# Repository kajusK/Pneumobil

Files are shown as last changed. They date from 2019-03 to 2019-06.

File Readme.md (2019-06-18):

Pneumobil control and telemetry system
======================================

This repository contains source code and board design for control system
of pneumobil racing car Falcon from Brno University of Technology.

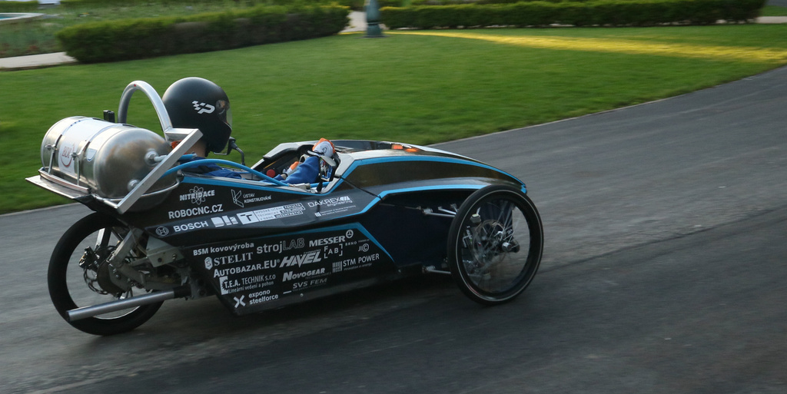
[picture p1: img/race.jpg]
race


Parts
-----
 * HMI - Human Machine Interface - LCD touch screen and telemetry board
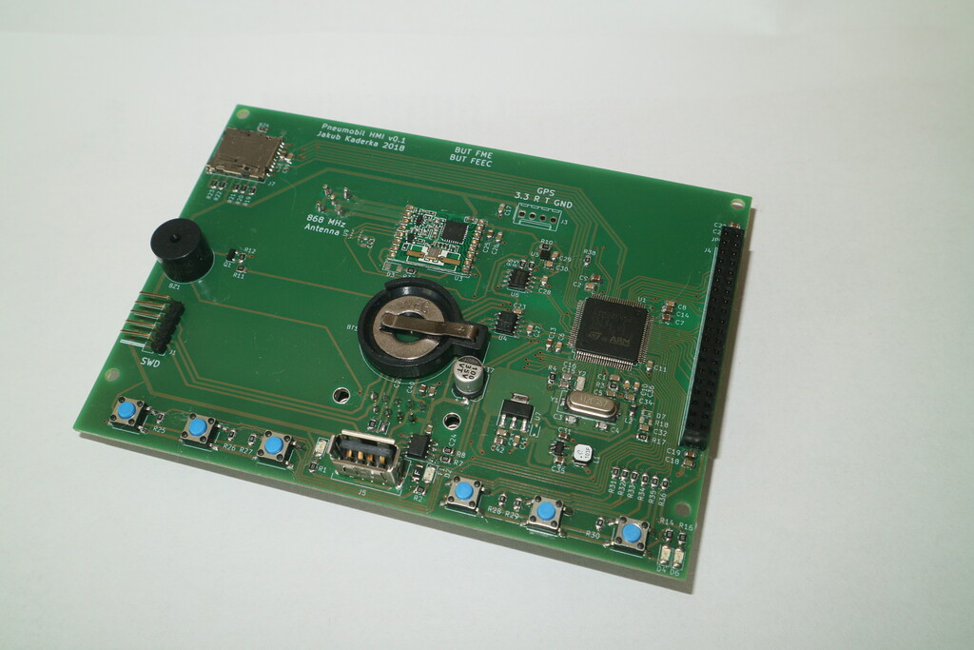
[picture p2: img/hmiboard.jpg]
hmi

 * ECU - Engine Control Unit - Control system of pneumatic propulsion system
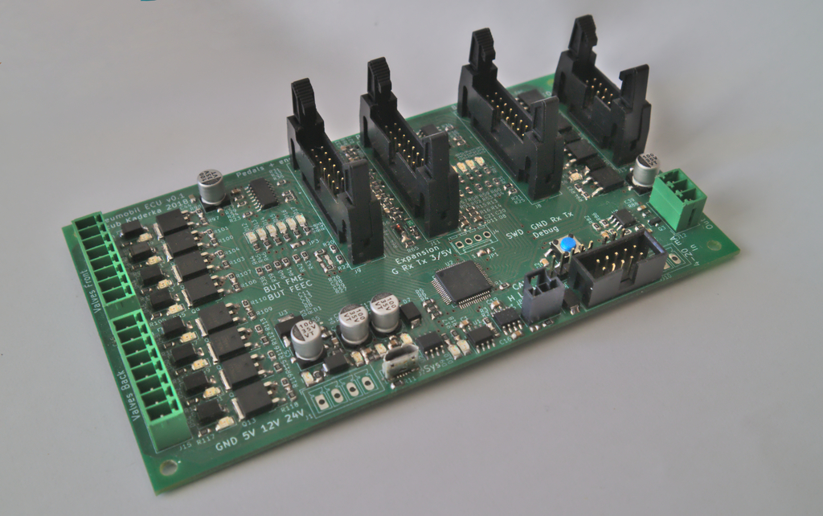
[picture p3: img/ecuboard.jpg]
ecu

 * SDU - Speed Display Unit
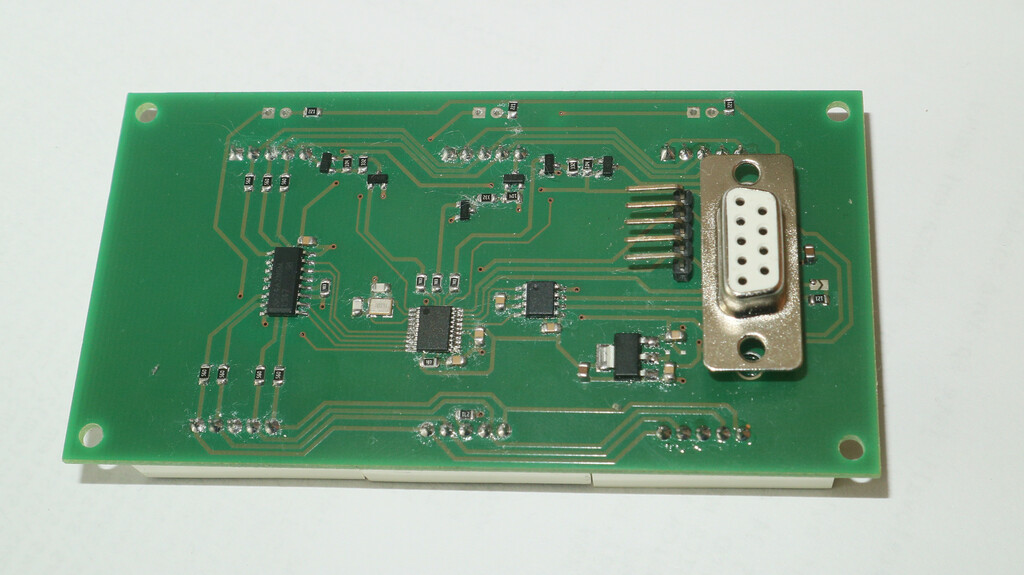
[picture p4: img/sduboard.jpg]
sdu

 * PSU - Power Supply Unit
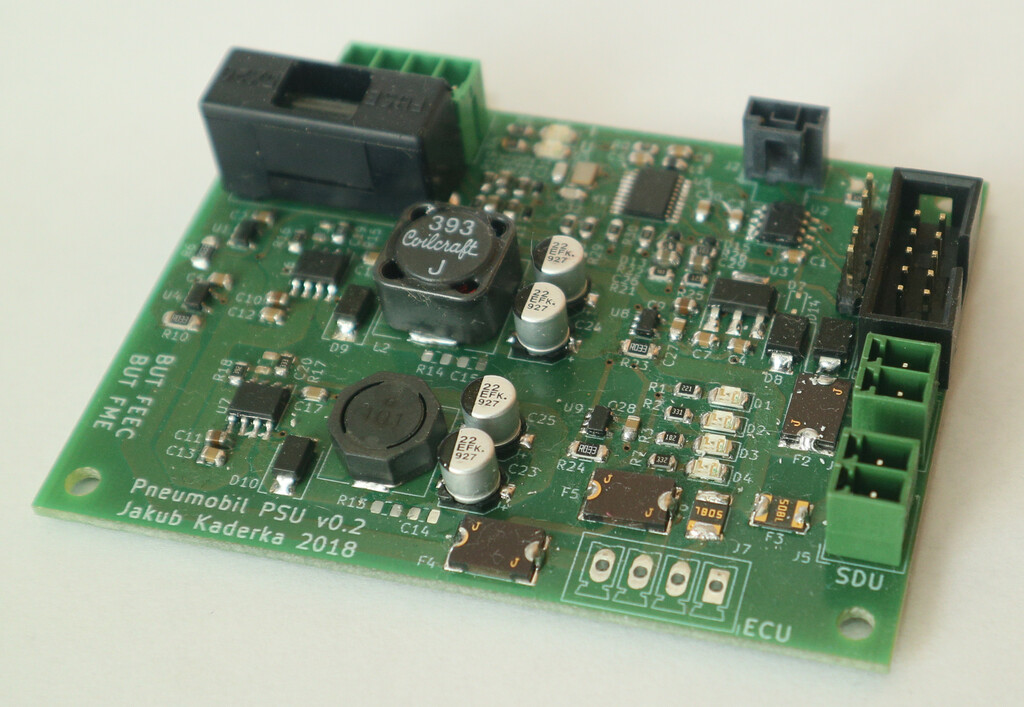
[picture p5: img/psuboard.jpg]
psu

 * Radio2usb - Telemetry receiving system
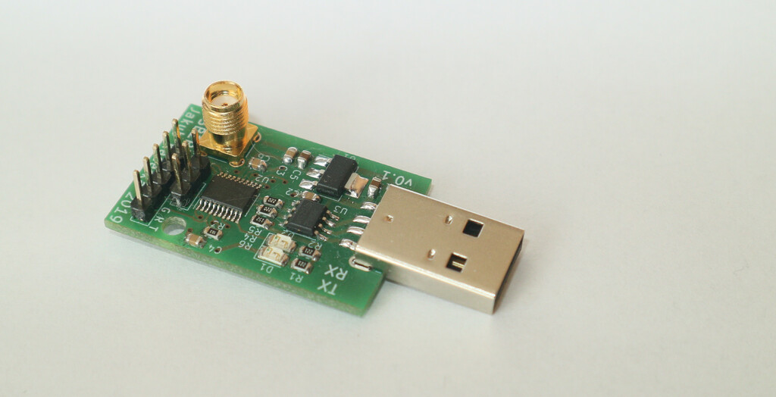
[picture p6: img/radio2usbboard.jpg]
r2usb


Description
-----------
Placement in the car
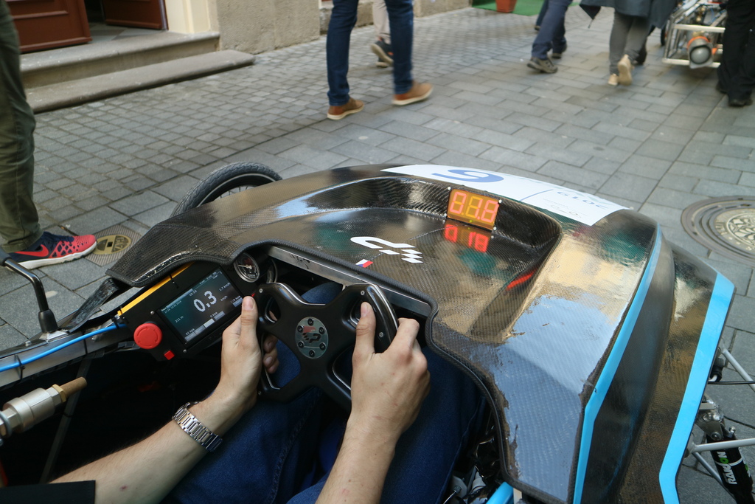
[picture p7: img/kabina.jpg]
cabin

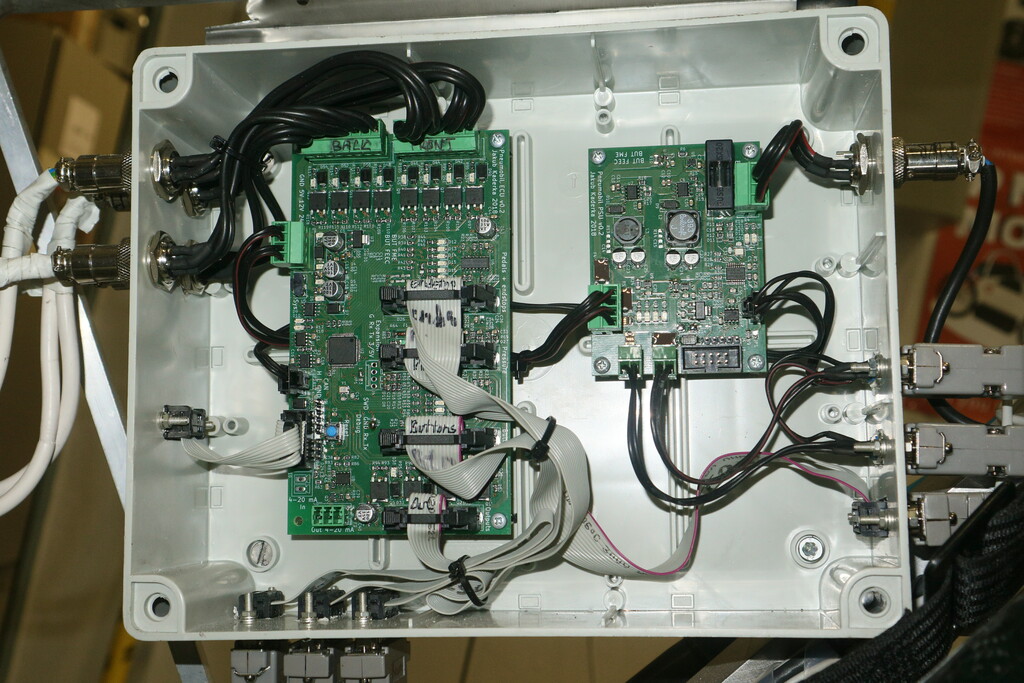
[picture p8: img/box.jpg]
box


Python telemetry program
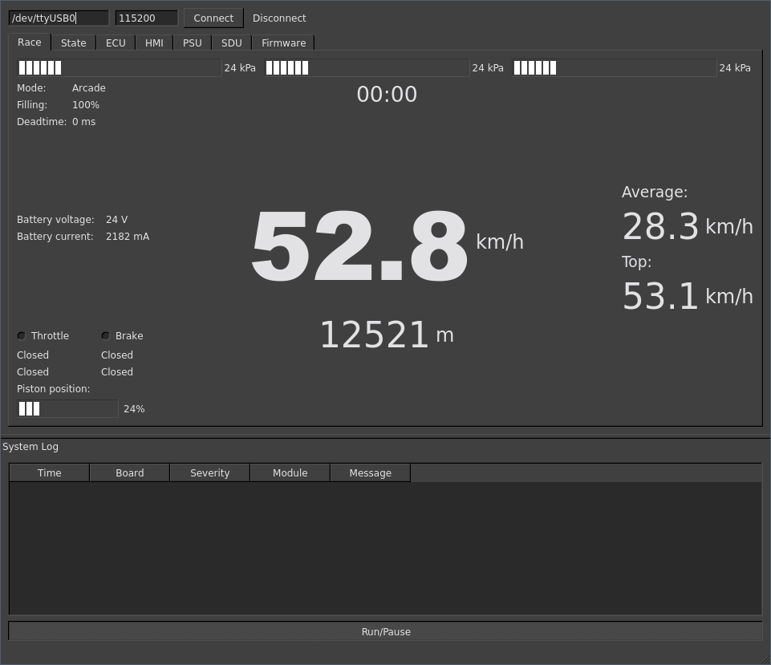
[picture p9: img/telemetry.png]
telemetry


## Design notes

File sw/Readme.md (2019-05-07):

Brief
=====

This directory contains various PC side tools to be used for development, code
generation, debugging, etc.

Directories
===========
generators
----------
Scripts from this directory are used to generate header files and definitions
from specifications in doc/specs

Run generators/genall.py to regenerate all generated sources

tools
-----
Various tools, e.g. CRC lookup table generation, code checking, etc.

telemetry
---------
Telemetry tool for displaying current car state transferred wirelessly, debug
interface,....

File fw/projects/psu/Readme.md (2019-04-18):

Setting option bits
===================

Pin PB8 serves as a BOOT0 pin by default, to use it as GPIO, option bits must
be configured - use STM32CubeProgrammer to uncheck Boot_Sel bit

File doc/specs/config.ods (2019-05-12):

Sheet: ECU_config
Name | Type | Default | Comment
piston_len | uint | 0 | Piston len in encoder steps
encoder_invert | bool | 0 | Invert direction of encoder counting
pneu_non_block | bool | 0 | Ignore checking pneu enabled
wheel_dia_mm | uint | 540 | Diameter of the wheel where the speed sensor is placed
pulses_per_wheel_rotation | uint | 60 | Amount of holes in the shade on the back wheel for speed measurement (pulses generated in single rotation)
sender_period_ms | uint | 10 | Send car state over can every x ms
filling_pct_long_dist | uint | 30 | Filling percentage for long distance race
deadtime_ms_long_dist | uint | 2000 | Deadtime for long distance race
filling_pct_arcade | uint | 95 | Filling percentage for arcade race
deadtime_ms_arcade | uint | 50 | Deadtime for arcade race
filling_pct_acceleration | uint | 100 | Acceleration filling percentage
deadtime_ms_acceleration | uint | 0 | Acceleration deadtime
endstop_invert | bool | 0 | Invert endstop polarity (1 means active low)
default_mode | uint | 0 | Default ecu mode after boot

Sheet: HMI_config
Name | Type | Default | Comment
lcd_rotate | bool | 0 | Flip lcd horizontally
backlight | uint | 100 | Default lcd backlight percentage
contrast | uint | 50 | Default LCD contrast
touch_ax | float | 0 | LCD calibration data
touch_bx | float | 0 | LCD calibration data
touch_cx | float | 0 | LCD calibration data
touch_ay | float | 0 | LCD calibration data
touch_by | float | 0 | LCD calibration data
touch_cy | float | 0 | LCD calibration data
log_period_ms | uint | 10 | Logging period on sd card in ms
rf_period_ms | uint | 500 | Telemetry sending period
rf_enabled | bool | 1 | If true, start sending rf data after boot
rf_power_dbm | float | 0 | RF power in dBm to be used for transmitting
arcade_deadtime_max_ms | uint | 2000 | Maximum length of deadtime in arcade mode
acceleration_deadtime_max_ms | uint | 2000 | Maximum length of deadtime in acceleration mode
long_dist_deadtime_max_ms | uint | 10000 | Maximum length of deadtime in long distance mode

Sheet: Common_config
Name | Type | Default | Comment
Log_severity |  |  | Loggin severities for various modules

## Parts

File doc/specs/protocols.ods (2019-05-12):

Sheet: UART msg
byte | 0 | 1 | 2…(n-1) | n
value | 0xff | len | payload | crc8

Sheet: CAN msg
Single part message
byte | 0-7
value | payload |  |  | max message length is 8 bytes
Multipart message (multipart bit set in ID)
First message
byte | 0 | 1 | 2-7
value | 0x00 | length | payload | msg_id starts at 0 and is incremented every frame
Other messages
byte | 0 | 1-7 (optional)
value | msg id | payload
Last multipart message
byte | 0 | 1-n | N+1
value | msg id | payload | CRC8

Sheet: CAN adressing
 |  | Lower number, higher ID
 | devices: | ID |  |  | Priority levels | Description
 | PC/programmer | 0x00 |  |  | 0 | critical errors and systém commands
 | PSU | 0x01 |  |  | 1 | Normal priority (car state and stuff)
 | HMI | 0x02 |  |  | 2 | usual log messages
 | ECU | 0x03 |  |  | 3 | debug messages
 | SDU | 0x04
 | Broadcast | 0x07 | (for destination only)
CAN Identifier
Bit | 0 | 1 | 2 | 3 | 4 | 5 | 6 | 7 | 8 | 9 | 10
Value | Priority |  | Source device |  | 0 | 0 | Destination | 0 | 0 |  | multipart msg

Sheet: Commands
ID | name | Description | Response | 0 | 1 | 2 | 3 | 4 | 5 | 6 |  | 0 | 1 | 2 | 3 | 4 | 5 | 6
Generic commands |  |  |  |  |  |  |  |  |  |  |  | Response
0x00 | system_status | Current systems status, sent periodically | 0 | Device ID | State | uptime (sec since boot) |  | core_temp | core_voltage
0x01 | set_log_mask | Set logging mask | 1 | Interface | System | Driver | Module | Comm | ECU | HMI | Power | COMM_OK
0x02 | get_log_mask | Get logging mask | 1 | Interface |  |  |  |  |  |  |  | Interface | System | Driver | Comm | Config | ECU | HMI
0x03 | set_config | Set configuration item | 1 | Item ID | Item type | value |  |  |  |  |  | COMM_OK
0x04 | get_config | Get config item value | 1 | Item ID | Item type |  |  |  |  |  |  | Item ID | Item type | value
0x05 | reset_config | Restart all config items to defaults | 1 | 0xdeadbeef |  |  |  |  |  |  |  | COMM_OK
0x06 | get_all_config | Get all config items | n
0x07 | log_message | System log message | 0 | source | log_severity | log message (up to max packet len)
Flash commands
0x10 | flash_version | Current info about flash |  | Device ID | ver_major | ver_minor | bck_major | bck_minor | Flash partition size
0x11 | get_flash_version | Get info about image stored
0x12 | flash_mode | Current flashing state |  | flash state | bytes_written |  |  |  | blocks_erased | packet seq latest
0x13 | flash_init | Initialize flashing sequence |  | ver_major | ver_minor | Image length |  |  |  | CRC
0x14 | flash_data | Send data to be flashed |  | seq_id | Data 0..128
0x15 | flash_finish | Finish flashing / cancel flash operation |  | (response in flash mode state)
0x16 | reboot | Reboot the device |  | 0xdeadbeef
ECU commands
0x20 | car_state | Current state of the car | 0 | speed |  | speed_avg |  | distance |  | race_mode
0x21 | car_io | Inputs and outputs of the ecu | 0 | valves state | endstops | car_inputs | gear
0x22 | pneu_state | Current state of the pneumatic circuit | 0 | press1 |  | press2 |  | press3 |  | piston_pos_pct
0x23 | gps_position | Car gps position |  | latitude |  |  | longitude |  |  | speed
0x24 | temps | Temperatures in pneumatic circuit | m | temp1 |  | temp2 |  | temp3
0x25 | start_race | Set pneumatic mode and start race | 1 | mode |  |  |  |  |  |  |  | COMM_OK
0x26 | ecu_debug | Debug mode IO control | 1 | valves | outputs |  |  |  |  |  |  | COMM_OK
0x27 | ecu_user_io | Set user controllable outputs | 1 | horn | brake | out1 | out2 |  |  |  |  | COMM_OK
0x28 | set_pneu_params | Setup filling and turnaround time | 1 | mode | filling | turnardound_ms |  |  |  |  |  | COMM_OK
0x29 | get_pneu_params | Read filling and turnaround time | 1 | mode |  |  |  |  |  |  |  | mode | filling | turnaround_ms
0x2a | get_pneu_vars | Read pneumatic systém values | 1 |  |  |  |  |  |  |  |  | piston_len
0x2b | pneu_reinit | Reset all pneumatic initialization data | 1 | 0xdeadbeef |  |  |  |  |  |  |  | COMM_OK
PSU commands
0x30 | battery_state | Current battery state | 0 | voltage1 |  | voltage2 |  | current |  | charge_perc
0x31 | psu_current | Currents to branches | 0 | Current 5V |  | Current 12V |  | Current 24V
0x32 | psu_voltage | Voltages of all branches | 0 | Voltage 5V |  | Voltage 12V |  | Voltage 24V
HMI commands
0x3a | telemetry | System telemetry (intended for RF link) | 0 | too many parameters

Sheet: Commands format
 | Command ID
bits | 7 | 6 | 5-0
 | response_to_cmd | error | 0x00-0x3f
 | 1 |  |  | Valve state
Error response | Error code |  |  | 0x00 | Closed
 | 0x00 | Response was ok |  | 0x01 | Input
 | 0x01 | Unsupported command |  | 0x02 | Output
 | 0x02 | Incorrect parameter length
 | 0x03 | Incorrect parameter content
System State
 | 0x00 | Booting
 | 0x01 | Normal
 | 0x02 | Debug
 | 0x03 | Error
Log interface
 | 0x00 | Can
 | 0x01 | Uart
Log mask
 | 0x00 | None
 | 0x01 | Error
 | 0x02 | Warning
 | 0x03 | Info
 | 0x04 | Debug
Flash state
 | 0x00 | Flash Idle
 | 0x01 | Flashing
 | 0x02 | Flash suceeded
 | 0x03 | CRC failed
 | 0x04 | Seq incorrrect
Config item type
 | 0x00 | Bool
 | 0x01 | Uint
 | 0x02 | Float
race mode
 | 0x00 | arcade
 | 0x02 | acceleration
 | 0x01 | Long distance
 | 0x03 | debug
valves state format
6-7 | 4-5 | 3-2 | 1-0
front1 | front2 | back1 | back2
Endstop format
1 | 0
front | back
car inputs format
3 | 2 | 1 | 0
shifting | horn | brake | throttle
ecu debug outputs
3 | 2 | 1 | 0
out2 | out1 | brake light | horn

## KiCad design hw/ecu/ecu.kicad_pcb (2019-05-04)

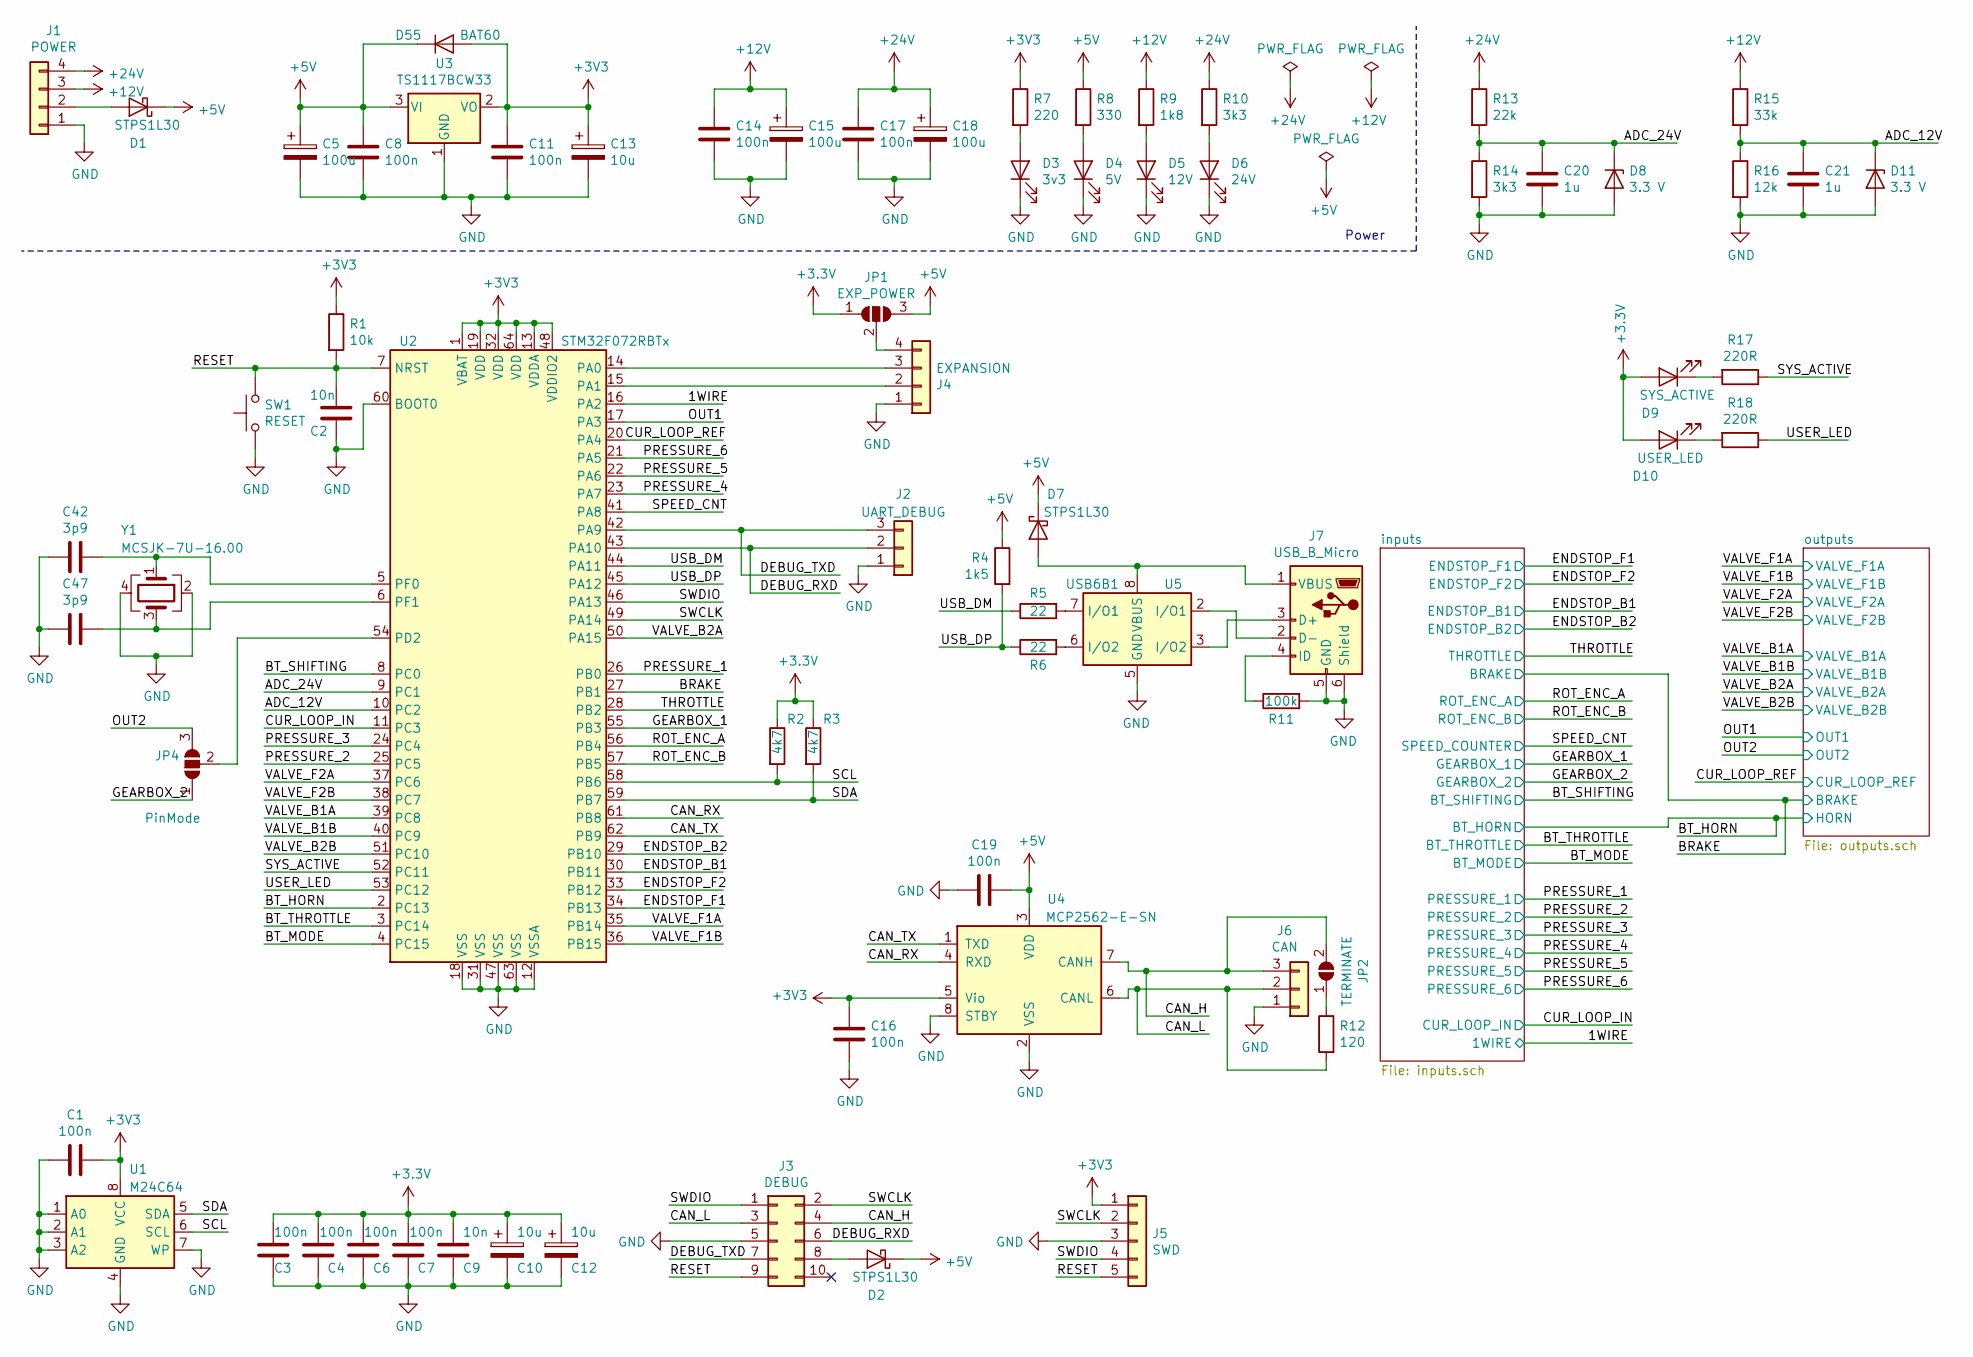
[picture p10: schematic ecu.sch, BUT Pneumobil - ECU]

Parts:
C1, C3, C4, C6, C7, C8, C11, C14, C16, C17, C19: 100n; C_0805_2012Metric
C2, C9: 10n; C_0805_2012Metric
C5, C15, C18: 100u; CP_Elec_6.3x7.7
C10, C12, C13: 10u; C_0805_2012Metric
C20, C21: 1u; C_0805_2012Metric
C42, C47: 3p9; C_0805_2012Metric
D1, D2, D7: STPS1L30; D_SMB
D3: 3v3; LED_1206_3216Metric
D4: 5V; LED_1206_3216Metric
D5: 12V; LED_1206_3216Metric
D6: 24V; LED_1206_3216Metric
D8, D11: 3.3 V; D_SOD-523
D9: SYS_ACTIVE; LED_1206_3216Metric
D10: USER_LED; LED_1206_3216Metric
D55: BAT60; D_SOD-323
J1: POWER; PhoenixContact_MCV_1,5_4-G-3.5_1x04_P3.50mm_Vertical
J2: UART_DEBUG; PinHeader_1x03_P2.54mm_Vertical
J3: DEBUG; IDC-Header_2x05_P2.54mm_Vertical
J4: EXPANSION; Molex_KK-254_AE-6410-04A_1x04_P2.54mm_Vertical
J5: SWD; PinHeader_1x05_P2.54mm_Vertical
J6: CAN; Molex_Nano-Fit_105309-xx03_1x03_P2.50mm_Vertical
J7: USB_B_Micro; USB_Micro-B_Molex-105133-0001
JP1: EXP_POWER; SolderJumper-3_P1.3mm_Open_Pad1.0x1.5mm_NumberLabels
JP2: TERMINATE; SolderJumper-2_P1.3mm_Open_Pad1.0x1.5mm
JP4: PinMode; SolderJumper-3_P1.3mm_Open_Pad1.0x1.5mm
R1: 10k; R_0805_2012Metric
R2, R3: 4k7; R_0805_2012Metric
R4: 1k5; R_0805_2012Metric
R5, R6: 22; R_0805_2012Metric
R7: 220; R_0805_2012Metric
R8: 330; R_0805_2012Metric
R9: 1k8; R_0805_2012Metric
R10, R14: 3k3; R_0805_2012Metric
R11: 100k; R_0805_2012Metric
R12: 120; R_0805_2012Metric
R13: 22k; R_0805_2012Metric
R15: 33k; R_0805_2012Metric
R16: 12k; R_0805_2012Metric
R17, R18: 220R; R_0805_2012Metric
SW1: RESET; SW_SPST_PTS645
U1: M24C64; SOIC-8_3.9x4.9mm_P1.27mm
U2: STM32F072RBTx; LQFP-64_10x10mm_P0.5mm
U3: TS1117BCW33; SOT-223-3_TabPin2
U4: MCP2562-E-SN; SOIC-8_3.9x4.9mm_P1.27mm
U5: USB6B1; SOIC-8_3.9x4.9mm_P1.27mm
Y1: MCSJK-7U-16.00; Crystal_SMD_3225-4Pin_3.2x2.5mm

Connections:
+5V: C5.1, C8.1, C19.1, D1.1 (K), D2.1 (K), D7.1 (K), D55.1 (K), JP1.3 (B), R4.1, R8.1, U3.3 (VI), U4.3 (VDD)
+12V: C14.1, C15.1, J1.3, R9.1, R15.1; also elsewhere on the board
+24V: C17.1, C18.1, J1.4, R10.1, R13.1; also elsewhere on the board
/1WIRE: U2.16 (PA2); also elsewhere on the board
/ADC_12V: C21.1, D11.1 (K), R15.2, R16.1, U2.10 (PC2)
/ADC_24V: C20.1, D8.1 (K), R13.2, R14.1, U2.9 (PC1)
/BRAKE: U2.27 (PB1); also elsewhere on the board
/BT_HORN: U2.2 (PC13); also elsewhere on the board
/BT_MODE: U2.4 (PC15); also elsewhere on the board
/BT_SHIFTING: U2.8 (PC0); also elsewhere on the board
/BT_THROTTLE: U2.3 (PC14); also elsewhere on the board
/CAN_H: J3.4, J6.3, JP2.2 (B), U4.7 (CANH)
/CAN_L: J3.3, J6.2, R12.2, U4.6 (CANL)
/CAN_RX: U2.61 (PB8), U4.4 (RXD)
/CAN_TX: U2.62 (PB9), U4.1 (TXD)
/CUR_LOOP_IN: U2.11 (PC3); also elsewhere on the board
/CUR_LOOP_REF: U2.20 (PA4); also elsewhere on the board
/DEBUG_RXD: J2.2, J3.6, U2.43 (PA10)
/DEBUG_TXD: J2.3, J3.7, U2.42 (PA9)
/ENDSTOP_B1: U2.30 (PB11); also elsewhere on the board
/ENDSTOP_B2: U2.29 (PB10); also elsewhere on the board
/ENDSTOP_F1: U2.34 (PB13); also elsewhere on the board
/ENDSTOP_F2: U2.33 (PB12); also elsewhere on the board
/GEARBOX_1: U2.55 (PB3); also elsewhere on the board
/GEARBOX_2: JP4.1 (A); also elsewhere on the board
/OUT1: U2.17 (PA3); also elsewhere on the board
/OUT2: JP4.3 (B); also elsewhere on the board
/PRESSURE_1: U2.26 (PB0); also elsewhere on the board
/PRESSURE_2: U2.25 (PC5); also elsewhere on the board
/PRESSURE_3: U2.24 (PC4); also elsewhere on the board
/PRESSURE_4: U2.23 (PA7); also elsewhere on the board
/PRESSURE_5: U2.22 (PA6); also elsewhere on the board
/PRESSURE_6: U2.21 (PA5); also elsewhere on the board
/RESET: C2.1, J3.9, J5.5, R1.2, SW1.2, U2.7 (NRST)
/ROT_ENC_A: U2.56 (PB4); also elsewhere on the board
/ROT_ENC_B: U2.57 (PB5); also elsewhere on the board
/SCL: R2.2, U1.6 (SCL), U2.58 (PB6)
/SDA: R3.2, U1.5 (SDA), U2.59 (PB7)
/SPEED_CNT: U2.41 (PA8); also elsewhere on the board
/SWCLK: J3.2, J5.2, U2.49 (PA14)
/SWDIO: J3.1, J5.4, U2.46 (PA13)
/SYS_ACTIVE: R17.1, U2.52 (PC11)
/THROTTLE: U2.28 (PB2); also elsewhere on the board
/USB_DM: R5.1, U2.44 (PA11)
/USB_DP: R4.2, R6.1, U2.45 (PA12)
/USER_LED: R18.1, U2.53 (PC12)
/VALVE_B1A: U2.39 (PC8); also elsewhere on the board
/VALVE_B1B: U2.40 (PC9); also elsewhere on the board
/VALVE_B2A: U2.50 (PA15); also elsewhere on the board
/VALVE_B2B: U2.51 (PC10); also elsewhere on the board
/VALVE_F1A: U2.35 (PB14); also elsewhere on the board
/VALVE_F1B: U2.36 (PB15); also elsewhere on the board
/VALVE_F2A: U2.37 (PC6); also elsewhere on the board
/VALVE_F2B: U2.38 (PC7); also elsewhere on the board
GND: C1.2, C2.2, C3.2, C4.2, C5.2, C6.2, C7.2, C8.2, C9.2, C10.2, C11.2, C12.2, C13.2, C14.2, C15.2, C16.2, C17.2, C18.2, C19.2, C20.2, C21.2, C42.2, C47.2, D3.1 (K), D4.1 (K), D5.1 (K), D6.1 (K), D8.2 (A), D11.2 (A), J1.1, J2.1, J3.5, J4.1, J5.3, J6.1, J7.5 (GND), J7.6 (Shield), R11.2, R14.2, R16.2, SW1.1, U1.1 (A0), U1.2 (A1), U1.3 (A2), U1.4 (GND), U1.7 (WP), U2.12 (VSSA), U2.18 (VSS), U2.31 (VSS), U2.47 (VSS), U2.60 (BOOT0), U2.63 (VSS), U3.1 (GND), U4.2 (VSS), U4.8 (STBY), U5.4 (GND), U5.5 (GND), Y1.2, Y1.4; also elsewhere on the board
unnamed: C42.1, U2.5 (PF0), Y1.1
unnamed: C47.1, U2.6 (PF1), Y1.3
unnamed: D1.2 (A), J1.2
unnamed: D2.2 (A), J3.8
unnamed: D3.2 (A), R7.2
unnamed: D4.2 (A), R8.2
unnamed: D5.2 (A), R9.2
unnamed: D6.2 (A), R10.2
unnamed: D7.2 (A), J7.1 (VBUS), U5.1 (VBUS), U5.8 (VBUS)
unnamed: D9.1 (K), R17.2
unnamed: D10.1 (K), R18.2
unnamed: J4.2, U2.15 (PA1)
unnamed: J4.3, U2.14 (PA0)
unnamed: J4.4, JP1.2 (C)
unnamed: J7.2 (D-), U5.2 (I/O1)
unnamed: J7.3 (D+), U5.3 (I/O2)
unnamed: J7.4 (ID), R11.1
unnamed: JP2.1 (A), R12.1
unnamed: JP4.2 (C), U2.54 (PD2)
unnamed: R5.2, U5.7 (I/O1)
unnamed: R6.2, U5.6 (I/O2)

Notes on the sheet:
Power

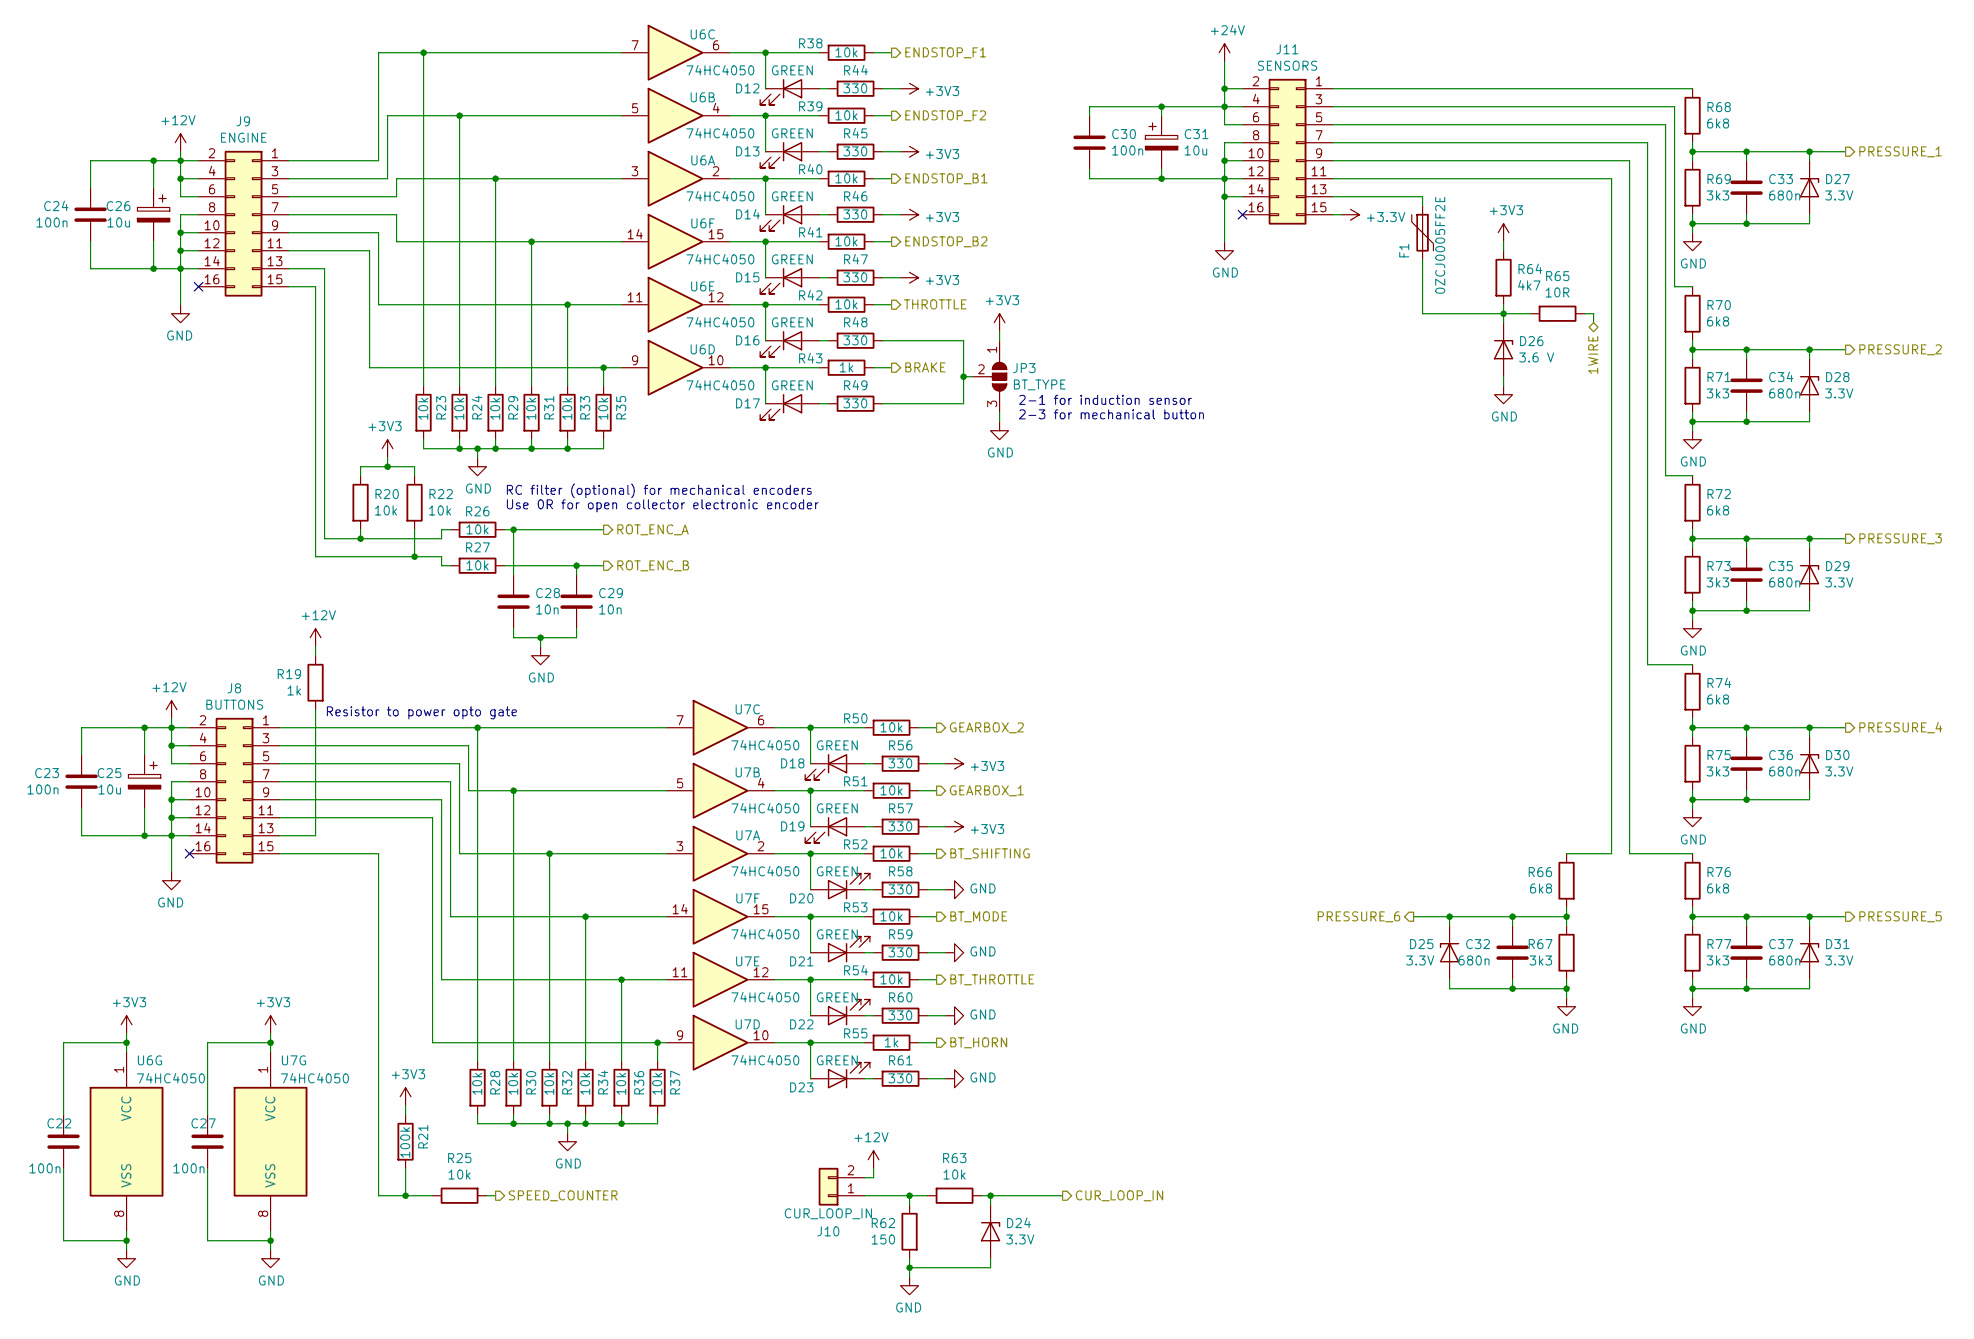
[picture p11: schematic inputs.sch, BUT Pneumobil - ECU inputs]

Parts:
C22, C23, C24, C27, C30: 100n; C_0805_2012Metric
C25, C26, C31: 10u; C_0805_2012Metric
C28, C29: 10n; C_0805_2012Metric
C32, C33, C34, C35, C36, C37: 680n; C_0805_2012Metric
D12, D13, D14, D15, D16, D17, D18, D19, D20, D21, D22, D23: GREEN; LED_1206_3216Metric
D24, D25, D27, D28, D29, D30, D31: 3.3V; D_SOD-523
D26: 3.6 V; D_MELF
F1: 0ZCJ0005FF2E; Fuse_1206_3216Metric
J8: BUTTONS; IDC-Header_2x08_P2.54mm_Vertical_Lock
J9: ENGINE; IDC-Header_2x08_P2.54mm_Vertical_Lock
J10: CUR_LOOP_IN; PhoenixContact_MCV_1,5_2-G-3.5_1x02_P3.50mm_Vertical
J11: SENSORS; IDC-Header_2x08_P2.54mm_Vertical_Lock
JP3: BT_TYPE; SolderJumper-3_P1.3mm_Open_Pad1.0x1.5mm
R19, R43, R55: 1k; R_0805_2012Metric
R20, R22, R23, R24, R25, R26, R27, R28, R29, R30, R31, R32, R33, R34, R35, R36, R37, R38, R39, R40, R41, R42, R50, R51, R52, R53, R54, R63: 10k; R_0805_2012Metric
R21: 100k; R_0805_2012Metric
R44, R45, R46, R47, R48, R49, R56, R57, R58, R59, R60, R61: 330; R_0805_2012Metric
R62: 150; R_0805_2012Metric
R64: 4k7; R_0805_2012Metric
R65: 10R; R_0805_2012Metric
R66, R68, R70, R72, R74, R76: 6k8; R_0805_2012Metric
R67, R69, R71, R73, R75, R77: 3k3; R_0805_2012Metric
U6, U7: 74HC4050; SOIC-16_3.9x9.9mm_P1.27mm

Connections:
+12V: C23.1, C24.1, C25.1, C26.1, J8.2, J8.4, J8.6, J9.2, J9.4, J9.6, J10.2, R19.1; also elsewhere on the board
+24V: C30.1, C31.1, J11.2, J11.4, J11.6; also elsewhere on the board
/1WIRE: R65.1; also elsewhere on the board
/BRAKE: R43.1; also elsewhere on the board
/BT_HORN: R55.1; also elsewhere on the board
/BT_MODE: R53.1; also elsewhere on the board
/BT_SHIFTING: R52.1; also elsewhere on the board
/BT_THROTTLE: R54.1; also elsewhere on the board
/CUR_LOOP_IN: D24.1 (K), R63.1; also elsewhere on the board
/ENDSTOP_B1: R40.1; also elsewhere on the board
/ENDSTOP_B2: R41.1; also elsewhere on the board
/ENDSTOP_F1: R38.1; also elsewhere on the board
/ENDSTOP_F2: R39.1; also elsewhere on the board
/GEARBOX_1: R51.1; also elsewhere on the board
/GEARBOX_2: R50.1; also elsewhere on the board
/PRESSURE_1: C33.1, D27.1 (K), R68.2, R69.1; also elsewhere on the board
/PRESSURE_2: C34.1, D28.1 (K), R70.2, R71.1; also elsewhere on the board
/PRESSURE_3: C35.1, D29.1 (K), R72.2, R73.1; also elsewhere on the board
/PRESSURE_4: C36.1, D30.1 (K), R74.2, R75.1; also elsewhere on the board
/PRESSURE_5: C37.1, D31.1 (K), R76.2, R77.1; also elsewhere on the board
/PRESSURE_6: C32.1, D25.1 (K), R66.2, R67.1; also elsewhere on the board
/ROT_ENC_A: C28.1, R26.1; also elsewhere on the board
/ROT_ENC_B: C29.1, R27.1; also elsewhere on the board
/SPEED_CNT: R25.2; also elsewhere on the board
/THROTTLE: R42.1; also elsewhere on the board
GND: C22.2, C23.2, C24.2, C25.2, C26.2, C27.2, C28.2, C29.2, C30.2, C31.2, C32.2, C33.2, C34.2, C35.2, C36.2, C37.2, D24.2 (A), D25.2 (A), D26.2 (A), D27.2 (A), D28.2 (A), D29.2 (A), D30.2 (A), D31.2 (A), J8.8, J8.10, J8.12, J8.14, J9.8, J9.10, J9.12, J9.14, J11.8, J11.10, J11.12, J11.14, JP3.3 (B), R23.2, R24.2, R28.2, R29.2, R30.2, R31.2, R32.2, R33.2, R34.2, R35.2, R36.2, R37.2, R58.1, R59.1, R60.1, R61.1, R62.2, R67.2, R69.2, R71.2, R73.2, R75.2, R77.2, U6.8 (VSS), U7.8 (VSS); also elsewhere on the board
unnamed: D12.1 (K), R38.2, U6.6
unnamed: D12.2 (A), R44.2
unnamed: D13.1 (K), R39.2, U6.4
unnamed: D13.2 (A), R45.2
unnamed: D14.1 (K), R40.2, U6.2
unnamed: D14.2 (A), R46.2
unnamed: D15.1 (K), R41.2, U6.15
unnamed: D15.2 (A), R47.2
unnamed: D16.1 (K), R42.2, U6.12
unnamed: D16.2 (A), R48.2
unnamed: D17.1 (K), R43.2, U6.10
unnamed: D17.2 (A), R49.2
unnamed: D18.1 (K), R50.2, U7.6
unnamed: D18.2 (A), R56.2
unnamed: D19.1 (K), R51.2, U7.4
unnamed: D19.2 (A), R57.2
unnamed: D20.1 (K), R58.2
unnamed: D20.2 (A), R52.2, U7.2
unnamed: D21.1 (K), R59.2
unnamed: D21.2 (A), R53.2, U7.15
unnamed: D22.1 (K), R60.2
unnamed: D22.2 (A), R54.2, U7.12
unnamed: D23.1 (K), R61.2
unnamed: D23.2 (A), R55.2, U7.10
unnamed: D26.1 (K), F1.2, R64.2, R65.2
unnamed: F1.1, J11.13
unnamed: J8.1, R28.1, U7.7
unnamed: J8.3, R30.1, U7.5
unnamed: J8.5, R32.1, U7.3
unnamed: J8.7, R34.1, U7.14
unnamed: J8.9, R36.1, U7.11
unnamed: J8.11, R37.1, U7.9
unnamed: J8.13, R19.2
unnamed: J8.15, R21.2, R25.1
unnamed: J9.1, R23.1, U6.7
unnamed: J9.3, R24.1, U6.5
unnamed: J9.5, R29.1, U6.3
unnamed: J9.7, R31.1, U6.14
unnamed: J9.9, R33.1, U6.11
unnamed: J9.11, R35.1, U6.9
unnamed: J9.13, R20.2, R26.2
unnamed: J9.15, R22.2, R27.2
unnamed: J10.1, R62.1, R63.2
unnamed: J11.1, R68.1
unnamed: J11.3, R70.1
unnamed: J11.5, R72.1
unnamed: J11.7, R74.1
unnamed: J11.9, R76.1
unnamed: J11.11, R66.1
unnamed: JP3.2 (C), R48.1, R49.1

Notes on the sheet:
Resistor to power opto gate
RC filter (optional) for mechanical encoders Use 0R for open collector electronic encoder
2-1 for induction sensor 2-3 for mechanical button

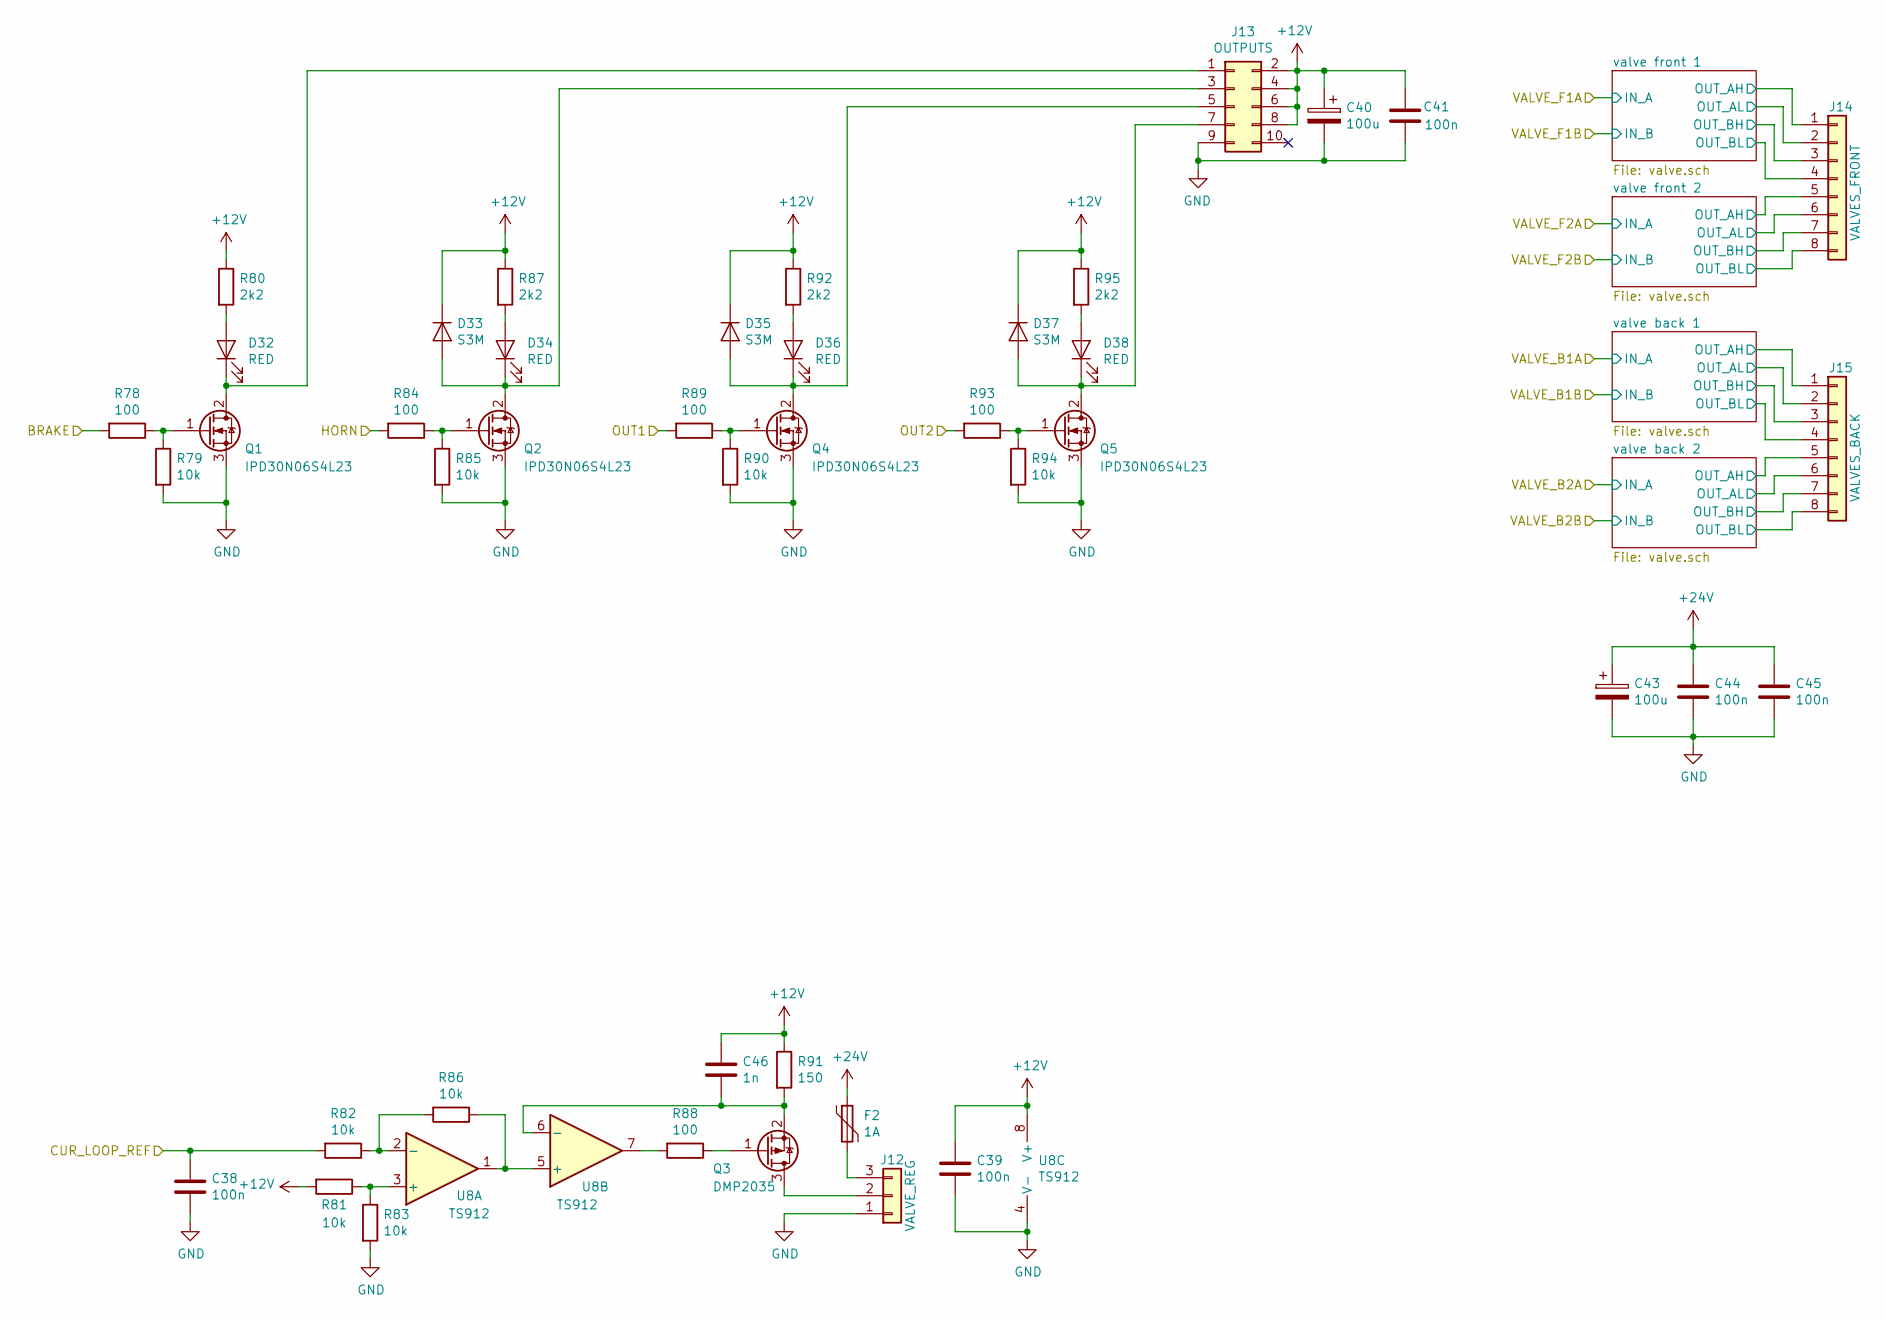
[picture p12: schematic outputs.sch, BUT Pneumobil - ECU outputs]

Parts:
C38, C39, C41, C44, C45: 100n; C_0805_2012Metric
C40, C43: 100u; CP_Elec_6.3x7.7
C46: 1n; C_0805_2012Metric
D32, D34, D36, D38: RED; LED_1206_3216Metric
D33, D35, D37: S3M; D_SMB
F2: 1A; Fuse_1206_3216Metric
J12: VALVE_REG; PhoenixContact_MCV_1,5_3-G-3.5_1x03_P3.50mm_Vertical
J13: OUTPUTS; IDC-Header_2x05_P2.54mm_Vertical_Lock
J14: VALVES_FRONT; PhoenixContact_MCV_1,5_8-G-3.5_1x08_P3.50mm_Vertical
J15: VALVES_BACK; PhoenixContact_MCV_1,5_8-G-3.5_1x08_P3.50mm_Vertical
Q1, Q2, Q4, Q5: IPD30N06S4L23; TO-252-2
Q3: DMP2035; SOT-23
R78, R84, R88, R89, R93: 100; R_0805_2012Metric
R79, R81, R82, R83, R85, R86, R90, R94: 10k; R_0805_2012Metric
R80, R87, R92, R95: 2k2; R_0805_2012Metric
R91: 150; R_0805_2012Metric
U8: TS912; SOIC-8_3.9x4.9mm_P1.27mm

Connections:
+12V: C39.1, C40.1, C41.1, C46.1, D33.1 (K), D35.1 (K), D37.1 (K), J13.2, J13.4, J13.6, J13.8, R80.1, R81.2, R87.1, R91.1, R92.1, R95.1, U8.8 (V+); also elsewhere on the board
+24V: C43.1, C44.1, C45.1, F2.1, J14.1, J14.3, J14.5, J14.7, J15.1, J15.3, J15.5, J15.7; also elsewhere on the board
/BRAKE: R78.2; also elsewhere on the board
/BT_HORN: R84.2; also elsewhere on the board
/CUR_LOOP_REF: C38.1, R82.2; also elsewhere on the board
/OUT1: R89.2; also elsewhere on the board
/OUT2: R93.2; also elsewhere on the board
/outputs/valve back 1/OUT_AL: J15.2; also elsewhere on the board
/outputs/valve back 1/OUT_BL: J15.4; also elsewhere on the board
/outputs/valve back 2/OUT_AL: J15.6; also elsewhere on the board
/outputs/valve back 2/OUT_BL: J15.8; also elsewhere on the board
/outputs/valve front 1/OUT_AL: J14.2; also elsewhere on the board
/outputs/valve front 1/OUT_BL: J14.4; also elsewhere on the board
/outputs/valve front 2/OUT_AL: J14.6; also elsewhere on the board
/outputs/valve front 2/OUT_BL: J14.8; also elsewhere on the board
GND: C38.2, C39.2, C40.2, C41.2, C43.2, C44.2, C45.2, J12.1, J13.9, Q1.3 (S), Q2.3 (S), Q4.3 (S), Q5.3 (S), R79.2, R83.2, R85.2, R90.2, R94.2, U8.4 (V-); also elsewhere on the board
unnamed: C46.2, Q3.2 (S), R91.2, U8.6 (-)
unnamed: D32.1 (K), J13.1, Q1.2 (D)
unnamed: D32.2 (A), R80.2
unnamed: D33.2 (A), D34.1 (K), J13.3, Q2.2 (D)
unnamed: D34.2 (A), R87.2
unnamed: D35.2 (A), D36.1 (K), J13.5, Q4.2 (D)
unnamed: D36.2 (A), R92.2
unnamed: D37.2 (A), D38.1 (K), J13.7, Q5.2 (D)
unnamed: D38.2 (A), R95.2
unnamed: F2.2, J12.3
unnamed: J12.2, Q3.3 (D)
unnamed: Q1.1 (G), R78.1, R79.1
unnamed: Q2.1 (G), R84.1, R85.1
unnamed: Q3.1 (G), R88.1
unnamed: Q4.1 (G), R89.1, R90.1
unnamed: Q5.1 (G), R93.1, R94.1
unnamed: R81.1, R83.1, U8.3 (+)
unnamed: R82.1, R86.2, U8.2 (-)
unnamed: R86.1, U8.1, U8.5 (+)
unnamed: R88.2, U8.7

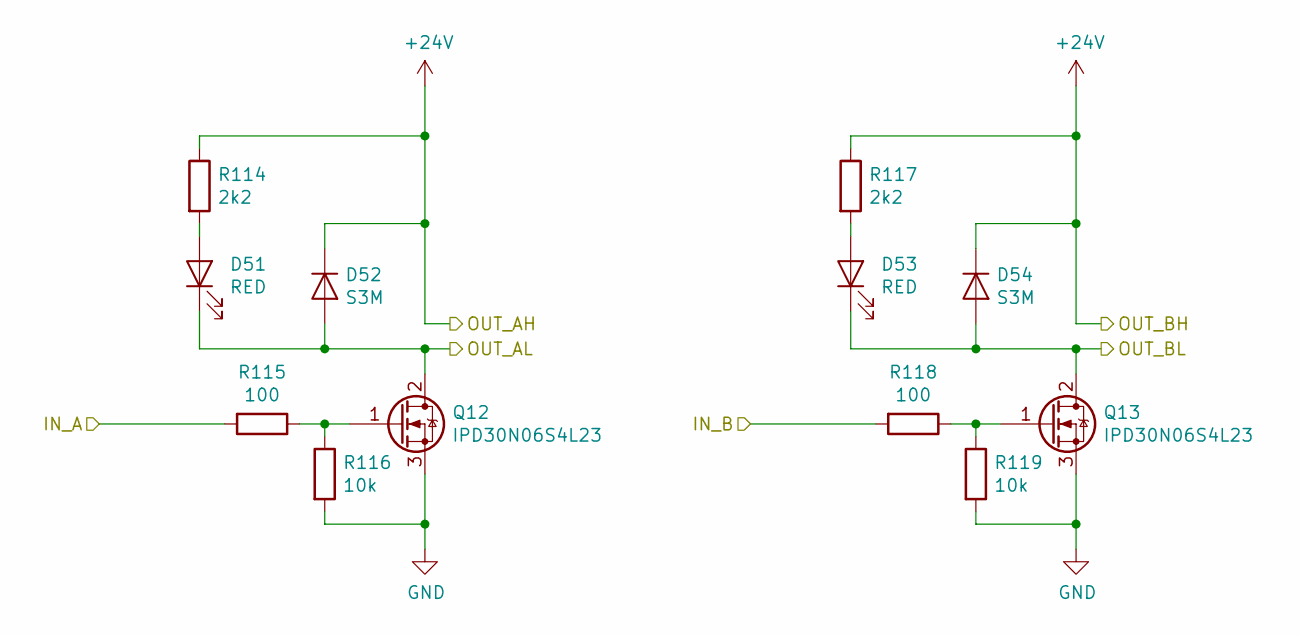
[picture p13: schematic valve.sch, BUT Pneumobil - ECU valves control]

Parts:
D39, D41: RED; LED_1206_3216Metric
D40, D42: S3M; D_SMB
Q6, Q7: IPD30N06S4L23; TO-252-2
R96, R99: 2k2; R_0805_2012Metric
R97, R100: 100; R_0805_2012Metric
R98, R101: 10k; R_0805_2012Metric

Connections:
+24V: D40.1 (K), D42.1 (K), R96.1, R99.1; also elsewhere on the board
/VALVE_F1A: R97.2; also elsewhere on the board
/VALVE_F1B: R100.2; also elsewhere on the board
/outputs/valve front 1/OUT_AL: D39.1 (K), D40.2 (A), Q6.2 (D); also elsewhere on the board
/outputs/valve front 1/OUT_BL: D41.1 (K), D42.2 (A), Q7.2 (D); also elsewhere on the board
GND: Q6.3 (S), Q7.3 (S), R98.2, R101.2; also elsewhere on the board
unnamed: D39.2 (A), R96.2
unnamed: D41.2 (A), R99.2
unnamed: Q6.1 (G), R97.1, R98.1
unnamed: Q7.1 (G), R100.1, R101.1

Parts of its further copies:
D43, D45, D47, D49, D51, D53: RED; LED_1206_3216Metric
D44, D46, D48, D50, D52, D54: S3M; D_SMB
Q8, Q9, Q10, Q11, Q12, Q13: IPD30N06S4L23; TO-252-2
R102, R105, R108, R111, R114, R117: 2k2; R_0805_2012Metric
R103, R106, R109, R112, R115, R118: 100; R_0805_2012Metric
R104, R107, R110, R113, R116, R119: 10k; R_0805_2012Metric

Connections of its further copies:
+24V: D44.1 (K), D46.1 (K), D48.1 (K), D50.1 (K), D52.1 (K), D54.1 (K), R102.1, R105.1, R108.1, R111.1, R114.1, R117.1; also elsewhere on the board
/VALVE_B1A: R109.2; also elsewhere on the board
/VALVE_B1B: R112.2; also elsewhere on the board
/VALVE_B2A: R115.2; also elsewhere on the board
/VALVE_B2B: R118.2; also elsewhere on the board
/VALVE_F2A: R103.2; also elsewhere on the board
/VALVE_F2B: R106.2; also elsewhere on the board
/outputs/valve back 1/OUT_AL: D47.1 (K), D48.2 (A), Q10.2 (D); also elsewhere on the board
/outputs/valve back 1/OUT_BL: D49.1 (K), D50.2 (A), Q11.2 (D); also elsewhere on the board
/outputs/valve back 2/OUT_AL: D51.1 (K), D52.2 (A), Q12.2 (D); also elsewhere on the board
/outputs/valve back 2/OUT_BL: D53.1 (K), D54.2 (A), Q13.2 (D); also elsewhere on the board
/outputs/valve front 2/OUT_AL: D43.1 (K), D44.2 (A), Q8.2 (D); also elsewhere on the board
/outputs/valve front 2/OUT_BL: D45.1 (K), D46.2 (A), Q9.2 (D); also elsewhere on the board
GND: Q8.3 (S), Q9.3 (S), Q10.3 (S), Q11.3 (S), Q12.3 (S), Q13.3 (S), R104.2, R107.2, R110.2, R113.2, R116.2, R119.2; also elsewhere on the board
unnamed: D43.2 (A), R102.2
unnamed: D45.2 (A), R105.2
unnamed: D47.2 (A), R108.2
unnamed: D49.2 (A), R111.2
unnamed: D51.2 (A), R114.2
unnamed: D53.2 (A), R117.2
unnamed: Q8.1 (G), R103.1, R104.1
unnamed: Q9.1 (G), R106.1, R107.1
unnamed: Q10.1 (G), R109.1, R110.1
unnamed: Q11.1 (G), R112.1, R113.1
unnamed: Q12.1 (G), R115.1, R116.1
unnamed: Q13.1 (G), R118.1, R119.1

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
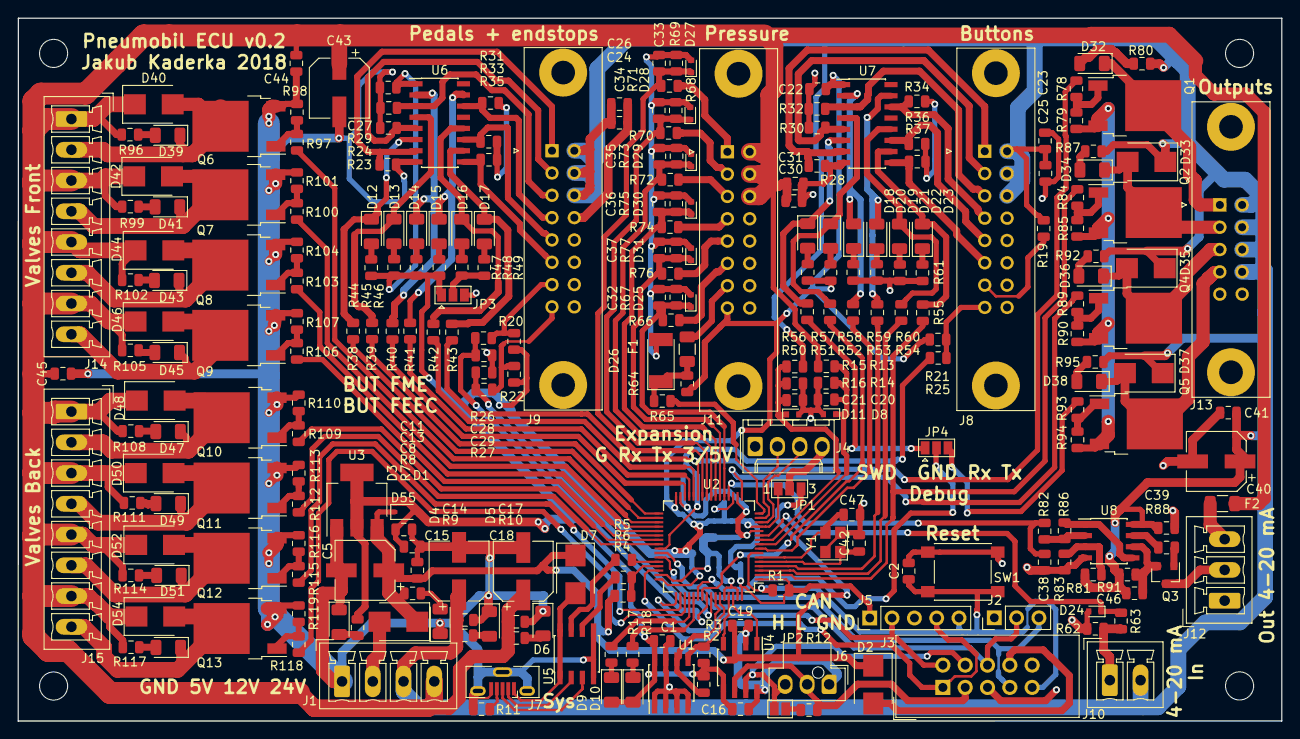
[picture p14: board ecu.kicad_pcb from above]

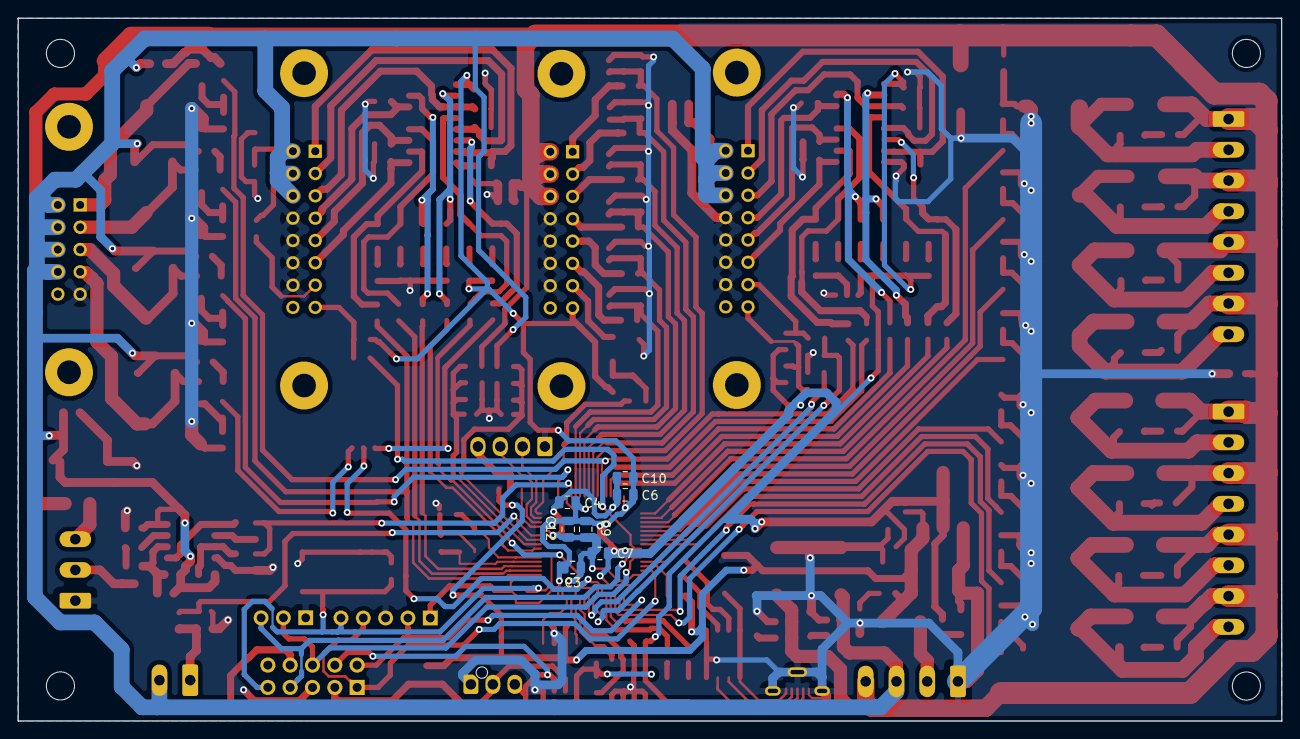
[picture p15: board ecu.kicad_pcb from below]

Board: 2 copper layers, 143.8 x 80.0 mm, 265 parts (7 on the bottom side), 171 nets.

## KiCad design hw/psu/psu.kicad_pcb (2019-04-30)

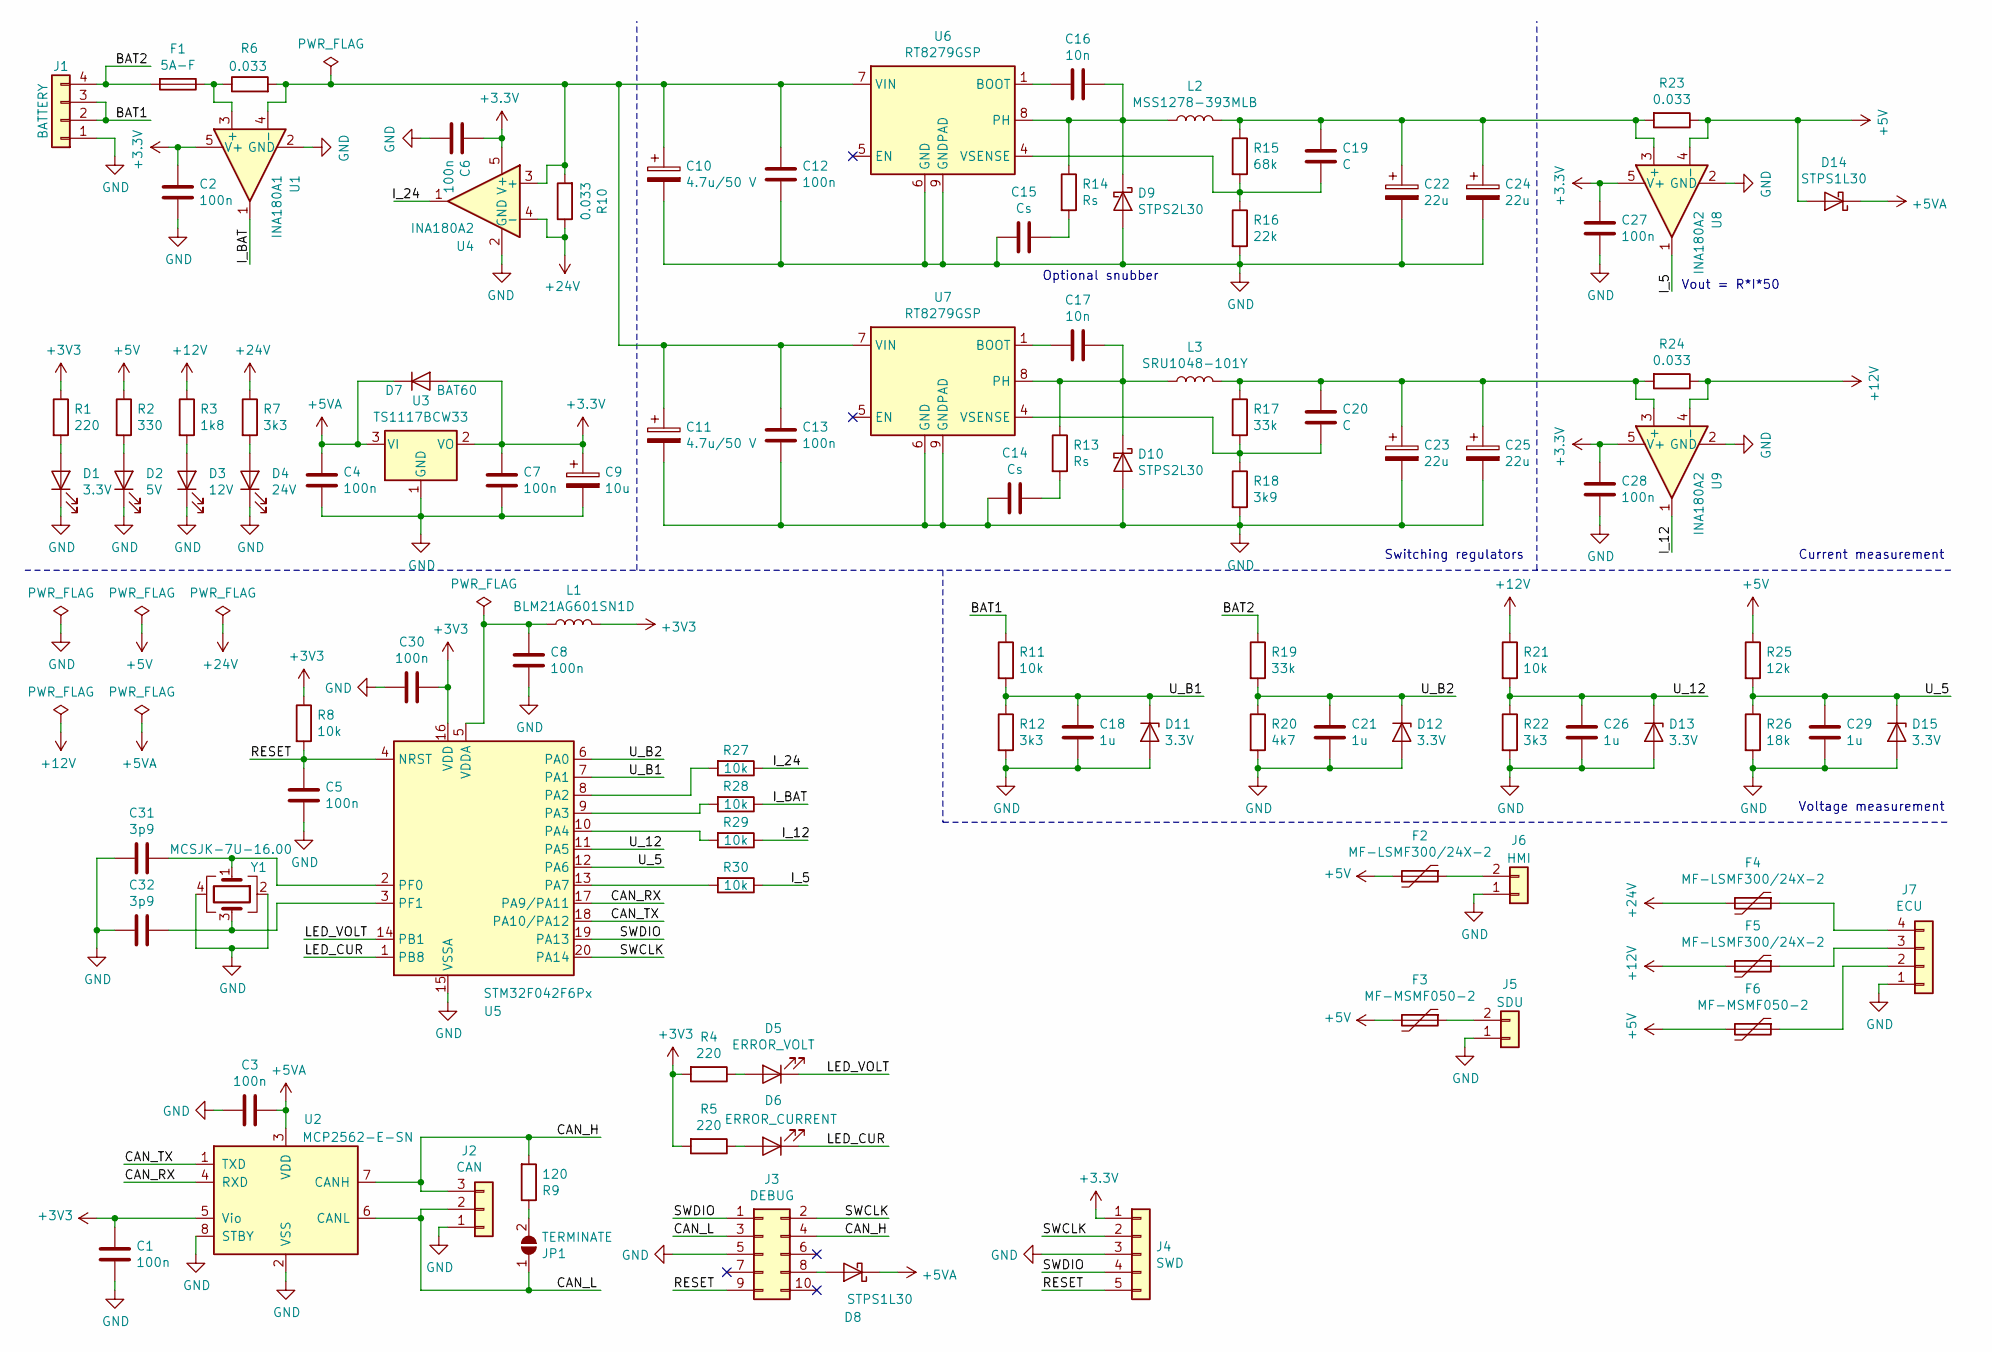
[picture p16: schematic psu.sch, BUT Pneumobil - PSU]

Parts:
C1, C2, C3, C4, C5, C6, C7, C8, C12, C13, C27, C28, C30: 100n; C_0805_2012Metric
C9: 10u; C_0805_2012Metric
C10, C11: 4.7u/50 V; C_0805_2012Metric
C14, C15: Cs; C_0805_2012Metric
C16, C17: 10n; C_0805_2012Metric
C18, C21, C26, C29: 1u; C_0805_2012Metric
C19, C20: C; C_0805_2012Metric
C22, C23, C24, C25: 22u; CP_Elec_5x5.8
C31, C32: 3p9; C_0805_2012Metric
D1: 3.3V; LED_1206_3216Metric
D2: 5V; LED_1206_3216Metric
D3: 12V; LED_1206_3216Metric
D4: 24V; LED_1206_3216Metric
D5: ERROR_VOLT; LED_1206_3216Metric
D6: ERROR_CURRENT; LED_1206_3216Metric
D7: BAT60; D_SOD-323
D8, D14: STPS1L30; D_SMB
D9, D10: STPS2L30; D_SMB
D11, D12, D13, D15: 3.3V; D_SOD-523
F1: 5A-F; Fuseholder_Cylinder-5x20mm_Schurter_0031_8201_Horizontal_Op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
F2, F4, F5: MF-LSMF300/24X-2; Fuse_2920_7451Metric
F3, F6: MF-MSMF050-2; Fuse_1812_4532Metric
J1: BATTERY; PhoenixContact_MCV_1,5_4-G-3.5_1x04_P3.50mm_Vertical
J2: CAN; Molex_Nano-Fit_105309-xx03_1x03_P2.50mm_Vertical
J3: DEBUG; IDC-Header_2x05_P2.54mm_Vertical
J4: SWD; PinHeader_1x05_P2.54mm_Vertical
J5: SDU; PhoenixContact_MCV_1,5_2-G-3.5_1x02_P3.50mm_Vertical
J6: HMI; PhoenixContact_MCV_1,5_2-G-3.5_1x02_P3.50mm_Vertical
J7: ECU; PhoenixContact_MCV_1,5_4-G-3.5_1x04_P3.50mm_Vertical
JP1: TERMINATE; SolderJumper-2_P1.3mm_Open_TrianglePad1.0x1.5mm
L1: BLM21AG601SN1D; L_0805_2012Metric
L2: MSS1278-393MLB; L_12x12mm_H8mm
L3: SRU1048-101Y; L_10.4x10.4_H4.8
R1, R4, R5: 220; R_0805_2012Metric
R2: 330; R_0805_2012Metric
R3: 1k8; R_0805_2012Metric
R6, R10, R23, R24: 0.033; R_1206_3216Metric
R7, R12, R22: 3k3; R_0805_2012Metric
R8, R11, R21, R27, R28, R29, R30: 10k; R_0805_2012Metric
R9: 120; R_0805_2012Metric
R13, R14: Rs; R_0805_2012Metric
R15: 68k; R_0805_2012Metric
R16: 22k; R_0805_2012Metric
R17, R19: 33k; R_0805_2012Metric
R18: 3k9; R_0805_2012Metric
R20: 4k7; R_0805_2012Metric
R25: 12k; R_0805_2012Metric
R26: 18k; R_0805_2012Metric
U1: INA180A1; SOT-23-5
U2: MCP2562-E-SN; SOIC-8_3.9x4.9mm_P1.27mm
U3: TS1117BCW33; SOT-223-3_TabPin2
U4, U8, U9: INA180A2; SOT-23-5
U5: STM32F042F6Px; TSSOP-20_4.4x6.5mm_P0.65mm
U6, U7: RT8279GSP; TI_SO-PowerPAD-8_ThermalVias
Y1: MCSJK-7U-16.00; Crystal_SMD_3225-4Pin_3.2x2.5mm

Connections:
+5V: D14.2 (A), F2.2, F3.2, F6.2, R2.1, R23.1, R25.1, U8.4 (-)
+5VA: C3.1, C4.1, D7.1 (K), D8.1 (K), D14.1 (K), U2.3 (VDD), U3.3 (VI)
+12V: F5.2, R3.1, R21.1, R24.1, U9.4 (-)
+24V: F4.2, R7.1, R10.1, U4.4 (-)
/BAT1: J1.2, J1.3, R11.1
/BAT2: F1.2, J1.4, R19.1
/CAN_H: J2.3, J3.4, R9.2, U2.7 (CANH)
/CAN_L: J2.2, J3.3, JP1.1 (A), U2.6 (CANL)
/CAN_RX: U2.4 (RXD), U5.17 (PA9/PA11)
/CAN_TX: U2.1 (TXD), U5.18 (PA10/PA12)
/I_5: R30.1, U8.1
/I_12: R29.1, U9.1
/I_24: R27.1, U4.1
/I_BAT: R28.1, U1.1
/LED_CUR: D6.1 (K), U5.1 (PB8)
/LED_VOLT: D5.1 (K), U5.14 (PB1)
/RESET: C5.1, J3.9, J4.5, R8.2, U5.4 (NRST)
/SWCLK: J3.2, J4.2, U5.20 (PA14)
/SWDIO: J3.1, J4.4, U5.19 (PA13)
/U_5: C29.1, D15.1 (K), R25.2, R26.1, U5.12 (PA6)
/U_12: C26.1, D13.1 (K), R21.2, R22.1, U5.11 (PA5)
/U_B1: C18.1, D11.1 (K), R11.2, R12.1, U5.7 (PA1)
/U_B2: C21.1, D12.1 (K), R19.2, R20.1, U5.6 (PA0)
GND: C1.2, C2.2, C3.2, C4.2, C5.2, C6.2, C7.2, C8.2, C9.2, C10.2, C11.2, C12.2, C13.2, C14.2, C15.2, C18.2, C21.2, C22.2, C23.2, C24.2, C25.2, C26.2, C27.2, C28.2, C29.2, C30.2, C31.2, C32.2, D1.1 (K), D2.1 (K), D3.1 (K), D4.1 (K), D9.2 (A), D10.2 (A), D11.2 (A), D12.2 (A), D13.2 (A), D15.2 (A), J1.1, J2.1, J3.5, J4.3, J5.1, J6.1, J7.1, R12.2, R16.2, R18.2, R20.2, R22.2, R26.2, U1.2 (GND), U2.2 (VSS), U2.8 (STBY), U3.1 (GND), U4.2 (GND), U5.15 (VSSA), U6.6 (GND), U6.9 (GNDPAD), U7.6 (GND), U7.9 (GNDPAD), U8.2 (GND), U9.2 (GND), Y1.2, Y1.4
unnamed: C8.1, L1.1, U5.5 (VDDA)
unnamed: C10.1, C11.1, C12.1, C13.1, R6.2, R10.2, U1.4 (-), U4.3 (+), U6.7 (VIN), U7.7 (VIN)
unnamed: C14.1, R13.2
unnamed: C15.1, R14.2
unnamed: C16.1, D9.1 (K), L2.1, R14.1, U6.8 (PH)
unnamed: C16.2, U6.1 (BOOT)
unnamed: C17.1, D10.1 (K), L3.1, R13.1, U7.8 (PH)
unnamed: C17.2, U7.1 (BOOT)
unnamed: C19.1, C22.1, C24.1, L2.2, R15.1, R23.2, U8.3 (+)
unnamed: C19.2, R15.2, R16.1, U6.4 (VSENSE)
unnamed: C20.1, C23.1, C25.1, L3.2, R17.1, R24.2, U9.3 (+)
unnamed: C20.2, R17.2, R18.1, U7.4 (VSENSE)
unnamed: C31.1, U5.2 (PF0), Y1.1
unnamed: C32.1, U5.3 (PF1), Y1.3
unnamed: D1.2 (A), R1.2
unnamed: D2.2 (A), R2.2
unnamed: D3.2 (A), R3.2
unnamed: D4.2 (A), R7.2
unnamed: D5.2 (A), R4.1
unnamed: D6.2 (A), R5.1
unnamed: D8.2 (A), J3.8
unnamed: F1.1, R6.1, U1.3 (+)
unnamed: F2.1, J6.2
unnamed: F3.1, J5.2
unnamed: F4.1, J7.4
unnamed: F5.1, J7.3
unnamed: F6.1, J7.2
unnamed: JP1.2 (B), R9.1
unnamed: R27.2, U5.8 (PA2)
unnamed: R28.2, U5.9 (PA3)
unnamed: R29.2, U5.10 (PA4)
unnamed: R30.2, U5.13 (PA7)

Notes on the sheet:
Vout = R*I*50
Optional snubber
Current measurement
Voltage measurement
Switching regulators

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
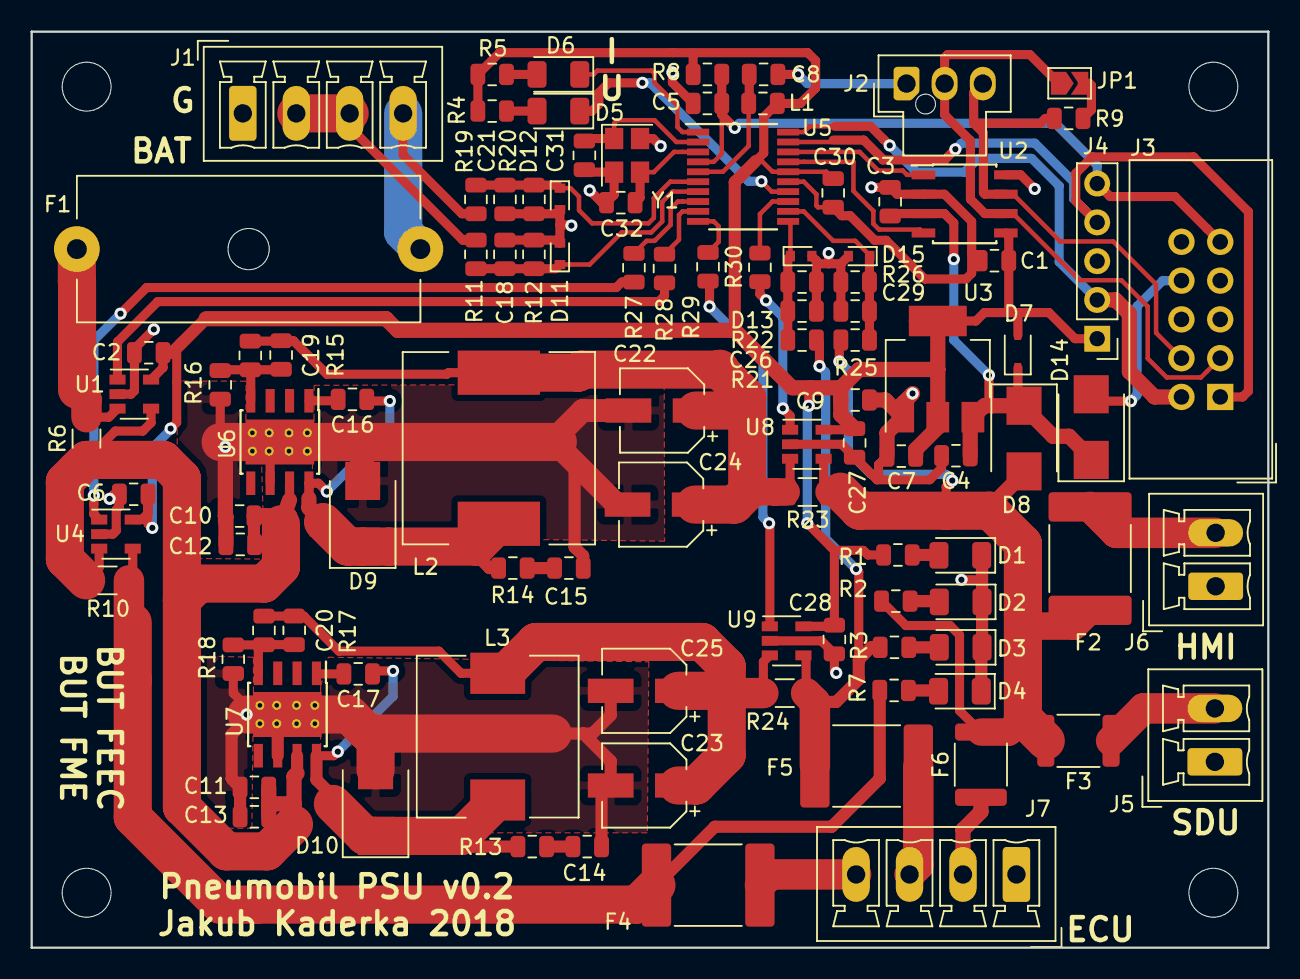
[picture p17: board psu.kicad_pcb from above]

Board: 2 copper layers, 81.0 x 60.0 mm, 104 parts (0 on the bottom side), 57 nets.

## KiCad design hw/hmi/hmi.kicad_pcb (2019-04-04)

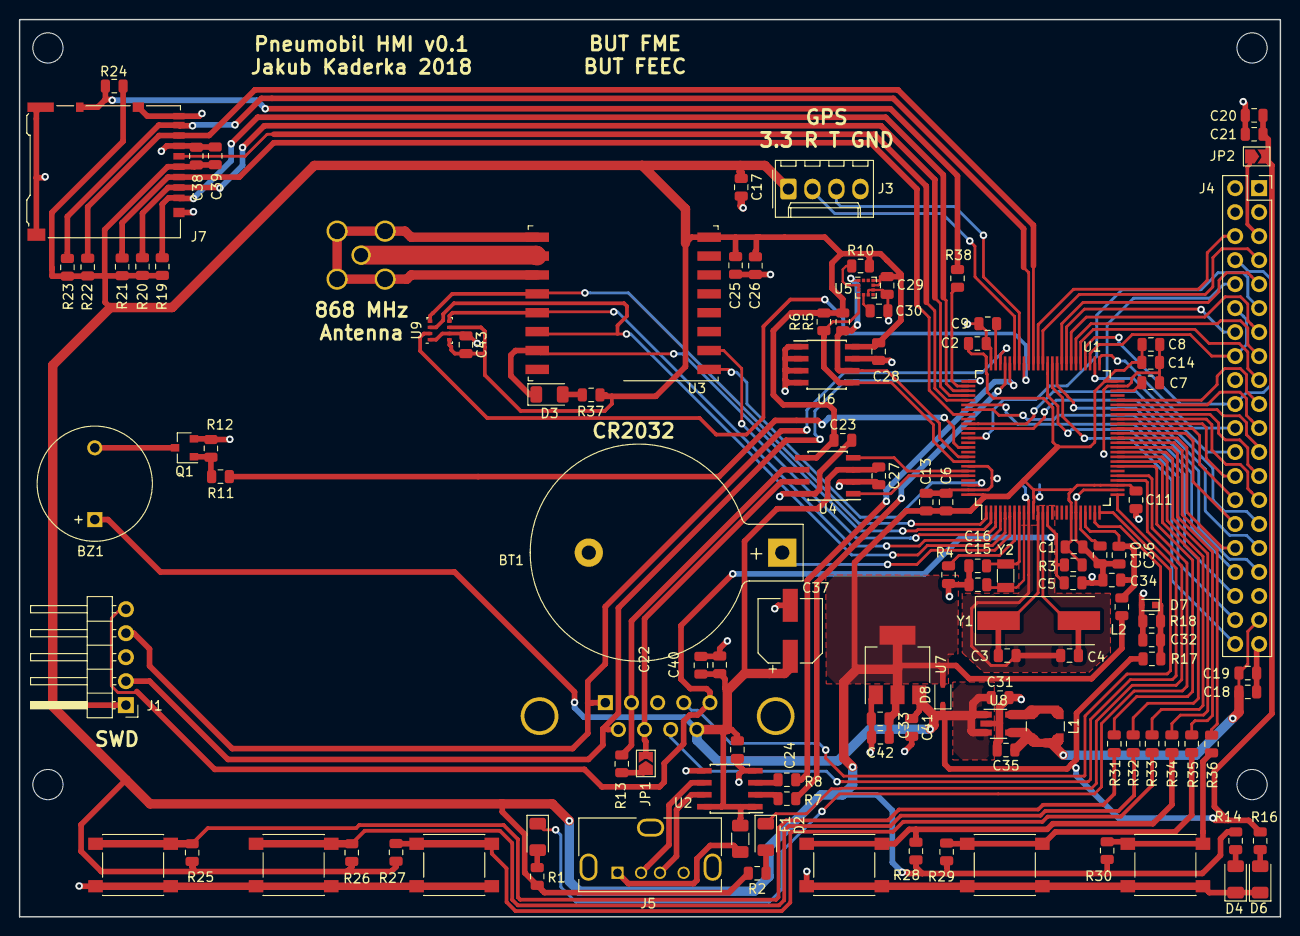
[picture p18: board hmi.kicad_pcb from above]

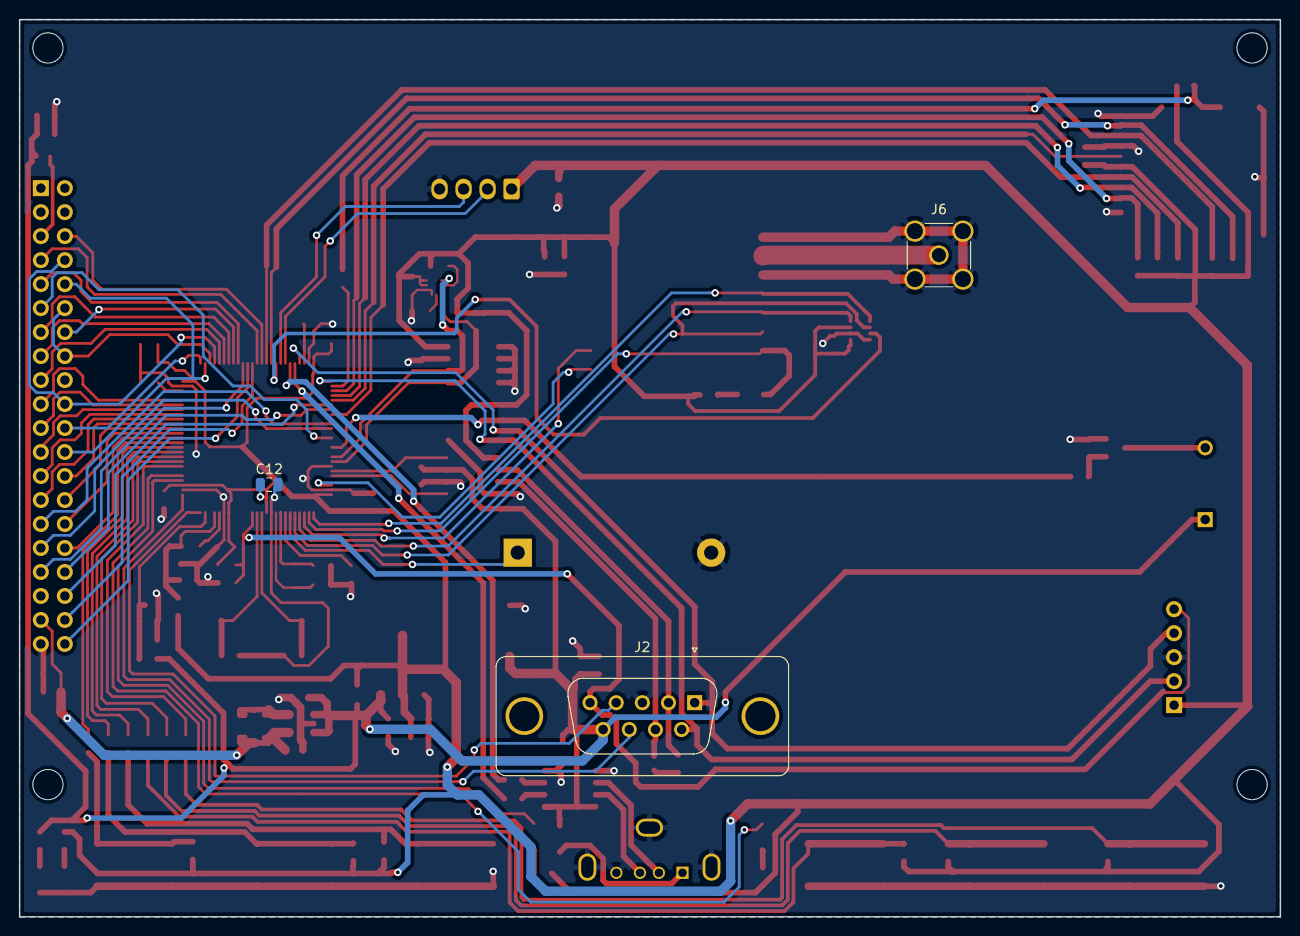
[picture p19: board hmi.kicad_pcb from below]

Board: 2 copper layers, 133.5 x 95.0 mm, 118 parts (3 on the bottom side), 106 nets.

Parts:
BT1: 3v3; BatteryHolder_Keystone_103_1x20mm
BZ1: Buzzer; MagneticBuzzer_ProSignal_ABI-009-RC
C1, C2, C5, C6, C8, C11, C12, C17, C18, C21, C23, C24, C26, C27, C28, C29, C30, C32, C33, C34, C39, C40, C41, C43: 100n; C_0805_2012Metric
C3, C4: 6p8; C_0805_2012Metric
C7, C9: 2.2u; C_0805_2012Metric
C10: 10n; C_0805_2012Metric
C13, C14, C19, C20, C22, C25, C38, C42: 10u; C_0805_2012Metric
C15, C16: 2p2; C_0805_2012Metric
C31, C35: 4.7u; C_0805_2012Metric
C36: 1u; C_0805_2012Metric
C37: 100u; CP_Elec_6.3x7.7
D1: GREEN; LED_1206_3216Metric
D2: RED; LED_1206_3216Metric
D3: RF_ACT; LED_1206_3216Metric
D4: 3.3 V; LED_1206_3216Metric
D6: 5 V; LED_1206_3216Metric
D7: 3.3 V; D_SOD-523
D8: BAT60; D_SOD-323
F1: 1206L050Y; Fuse_1206_3216Metric
J1: SWD; PinHeader_1x05_P2.54mm_Horizontal
J2: INTERFACE; DSUB-9_Female_Vertical_P2.77x2.84mm_MountingHoles
J3: GPS; Molex_KK-254_AE-6410-04A_1x04_P2.54mm_Vertical
J4: SSD1963_LCD; PinSocket_2x20_P2.54mm_Vertical
J5: USB; USB_A_Molex_105057_Vertical
J6: Antenna; SMA_Amphenol_132134-11_Vertical
J7: Micro_SD_Card_Det_Hirose_DM3AT; microSD_HC_Hirose_DM3AT-SF-PEJM5
JP1: TERMINATE; SolderJumper-2_P1.3mm_Open_TrianglePad1.0x1.5mm
JP2: MODEL2; SolderJumper-2_P1.3mm_Open_TrianglePad1.0x1.5mm
L1: LPS4018-103MRB; L_Coilcraft_LPS4018
L2: BLM21AG601SN1D; L_0805_2012Metric
Q1: BC847; SOT-23
R1, R2, R14, R37: 220; R_0805_2012Metric
R3, R24, R25, R26, R27, R28, R29, R30, R31, R32, R33, R34, R35, R36, R38: 10k; R_0805_2012Metric
R4, R12: 100k; R_0805_2012Metric
R5, R6, R17: 4k7; R_0805_2012Metric
R7, R8: 22R; R_0805_2012Metric
R10, R11: 1k; R_0805_2012Metric
R13: 120; R_0805_2012Metric
R16: 470; R_0805_2012Metric
R18: 9k1; R_0805_2012Metric
R19, R20, R21, R22, R23: 47k; R_0805_2012Metric
SW2: BTL1; SW_SPST_PTS645
SW3: BTL2; SW_SPST_PTS645
SW4: BTL3; SW_SPST_PTS645
SW5: BTR1; SW_SPST_PTS645
SW6: BTR2; SW_SPST_PTS645
SW7: BTR3; SW_SPST_PTS645
U1: STM32F412VETx; LQFP-100_14x14mm_P0.5mm
U2: USB6B1; SOIC-8_3.9x4.9mm_P1.27mm
U3: RFM69HW; HOPERF_RFM69HW
U4: MCP2562-E-SN; SOIC-8_3.9x4.9mm_P1.27mm
U5: LSM303C; LGA-12_2x2mm_P0.5mm
U6: M24C64; SOIC-8_3.9x4.9mm_P1.27mm
U7: TS1117BCW33; SOT-223-3_TabPin2
U8: MCP1603T-330; TSOT-23-5
U9: BME280; Bosch_LGA-8_2.5x2.5mm_P0.65mm_ClockwisePinNumbering
Y1: ABLS2-12.000MHZ-D4Y; Crystal_SMD_HC49-SD
Y2: ABS07-166-32.768KHZ-T; Crystal_SMD_3215-2Pin_3.2x1.5mm

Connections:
+3.3VADC: C34.1, C36.1, L2.2, U1.22
+3.3VP: C18.1, C19.1, C35.1, J4.37, L1.2, U8.4
+3V3: C1.1, C2.1, C6.1, C8.1, C11.1, C12.1, C13.1, C14.1, C17.1, C23.1, C25.1, C26.2, C28.1, C29.2, C33.1, C38.1, C39.1, C42.1, C43.2, D8.2, J1.1, J3.1, J7.4, L2.1, R1.2, R2.2, R3.1, R5.1, R6.1, R10.2, R14.1, R19.1, R20.1, R21.1, R22.1, R23.1, R24.1, R25.1, R26.1, R27.1, R28.1, R29.1, R30.1, R37.1, U1.11, U1.19, U1.28, U1.50, U1.75, U1.100, U3.8, U4.5, U5.9, U5.10, U6.8, U7.2, U9.6, U9.8
+5V: BZ1.1, C20.1, C21.1, C22.1, C24.1, C27.1, C31.1, C37.1, C40.1, C41.1, D8.1, F1.2, J2.9, JP2.2, R16.1, R17.1, U2.1, U2.8, U4.3, U7.3, U8.1, U8.3
/ADC_5V: C32.1, D7.1, R17.2, R18.1, U1.24
/BME_CS: U1.67, U9.2
/BTL1: R31.1, U1.32
/BTL2: R32.1, U1.33
/BTL3: R33.1, U1.34
/BTR1: R34.1, U1.35
/BTR2: R35.1, U1.36
/BTR3: R36.1, U1.37
/BUZZER: R11.2, U1.90
/CAN_H: J2.7, JP1.2, U4.7
/CAN_L: J2.2, R13.2, U4.6
/CAN_RX: U1.95, U4.4
/CAN_TX: U1.96, U4.1
/DEBUG_RX: J2.8, U1.26
/DEBUG_TX: J2.4, U1.25
/GPS_RX: J3.2, U1.69
/GPS_TX: J3.3, U1.68
/LCD_CS: J4.11, U1.88
/LCD_DB0: J4.40, U1.61
/LCD_DB1: J4.38, U1.62
/LCD_DB2: J4.36, U1.81
/LCD_DB3: J4.34, U1.82
/LCD_DB4: J4.32, U1.38
/LCD_DB5: J4.30, U1.39
/LCD_DB6: J4.28, U1.40
/LCD_DB7: J4.26, U1.41
/LCD_DB8: J4.27, U1.42
/LCD_DB9: J4.25, U1.43
/LCD_DB10: J4.23, U1.44
/LCD_DB11: J4.21, U1.45
/LCD_DB12: J4.19, U1.46
/LCD_DB13: J4.17, U1.55
/LCD_DB14: J4.15, U1.56
/LCD_DB15: J4.13, U1.57
/LCD_F_CS: J4.9, U1.59
/LCD_RD: J4.29, U1.85
/LCD_REST: J4.7, U1.63
/LCD_RS: J4.33, U1.60
/LCD_RW: J4.31, U1.86
/LCD_SD_CLK: J4.10, J4.24, U1.52
/LCD_SD_CS: J4.6, U1.64
/LCD_SD_DIN: J4.8, J4.20, U1.54
/LCD_SD_DO: J4.12, J4.16, U1.53
/LCD_T_CS: J4.22, U1.51
/LCD_T_IRQ: J4.14, U1.58
/LED_SYS_ACT: D1.1, U1.30
/LED_USER: D2.1, U1.29
/RESET: C5.1, J1.5, J2.5, R3.2, U1.14
/RFM_CS: D3.1, U1.2, U3.15
/RFM_IRQ: U1.3, U3.2
/RFM_RESET: U1.98, U3.1
/SCL: R5.2, U1.92, U5.1, U6.6
/SDA: R6.2, U1.93, U5.4, U6.5
/SDIO_CLK: J7.5, U1.80
/SDIO_CMD: J7.3, R21.2, U1.83
/SDIO_D0: J7.7, R22.2, U1.65
/SDIO_D1: J7.8, R23.2, U1.66
/SDIO_D2: J7.1, R19.2, U1.78
/SDIO_D3: J7.2, R20.2, U1.79
/SD_DETECT: R38.2, U1.77
/SPI4_MISO: U1.4, U3.13, U9.5
/SPI4_MOSI: U1.5, U3.14, U9.3
/SPI4_SCK: U1.1, U3.12, U9.4
/SWCLK: J1.2, J2.6, U1.76
/SWDIO: J1.4, J2.1, U1.72
/USB_DM: R8.2, U1.70
/USB_DP: R7.2, U1.71
GND: BT1.2, C1.2, C2.2, C3.2, C4.2, C5.2, C6.2, C7.1, C8.2, C9.1, C10.2, C11.2, C12.2, C13.2, C14.2, C15.2, C16.2, C17.2, C18.2, C19.2, C20.2, C21.2, C22.2, C23.2, C24.2, C25.2, C26.1, C27.2, C28.2, C29.1, C30.2, C31.2, C32.2, C33.2, C34.2, C35.2, C36.2, C37.2, C38.2, C39.2, C40.2, C41.2, C42.2, C43.1, D4.1, D6.1, D7.2, J1.3, J2.3, J3.4, J4.39, J5.4, J5.5, J6.2, J7.6, J7.9, J7.11, Q1.2, R4.2, R12.2, R18.2, SW2.1, SW3.1, SW4.1, SW5.1, SW6.1, SW7.1, U1.10, U1.20, U1.27, U1.49, U1.74, U1.94, U1.99, U2.4, U2.5, U3.9, U3.11, U4.2, U4.8, U5.6, U5.8, U6.1, U6.2, U6.3, U6.4, U6.7, U7.1, U8.2, U9.1, U9.7
unnamed: BT1.1, U1.6
unnamed: BZ1.2, Q1.3
unnamed: C3.1, U1.12, Y1.1
unnamed: C4.1, U1.13, Y1.2
unnamed: C7.2, U1.48
unnamed: C9.2, U1.73
unnamed: C10.1, U1.21
unnamed: C15.1, U1.9, Y2.1
unnamed: C16.1, U1.8, Y2.2
unnamed: C30.1, U5.5
unnamed: D1.2, R1.1
unnamed: D2.2, R2.1
unnamed: D3.2, R37.2
unnamed: D4.2, R14.2
unnamed: D6.2, R16.2
unnamed: F1.1, J5.1
unnamed: J4.5, JP2.1
unnamed: J5.2, U2.6
unnamed: J5.3, U2.7
unnamed: J6.1, U3.10
unnamed: J7.10, R24.2, R38.1
unnamed: JP1.1, R13.1
unnamed: L1.1, U8.5
unnamed: Q1.1, R11.1, R12.1
unnamed: R4.1, U1.7
unnamed: R7.1, U2.2
unnamed: R8.1, U2.3
unnamed: R10.1, U5.2, U5.3
unnamed: R25.2, R31.2, SW2.2
unnamed: R26.2, R32.2, SW3.2
unnamed: R27.2, R33.2, SW4.2
unnamed: R28.2, R34.2, SW5.2
unnamed: R29.2, R35.2, SW6.2
unnamed: R30.2, R36.2, SW7.2

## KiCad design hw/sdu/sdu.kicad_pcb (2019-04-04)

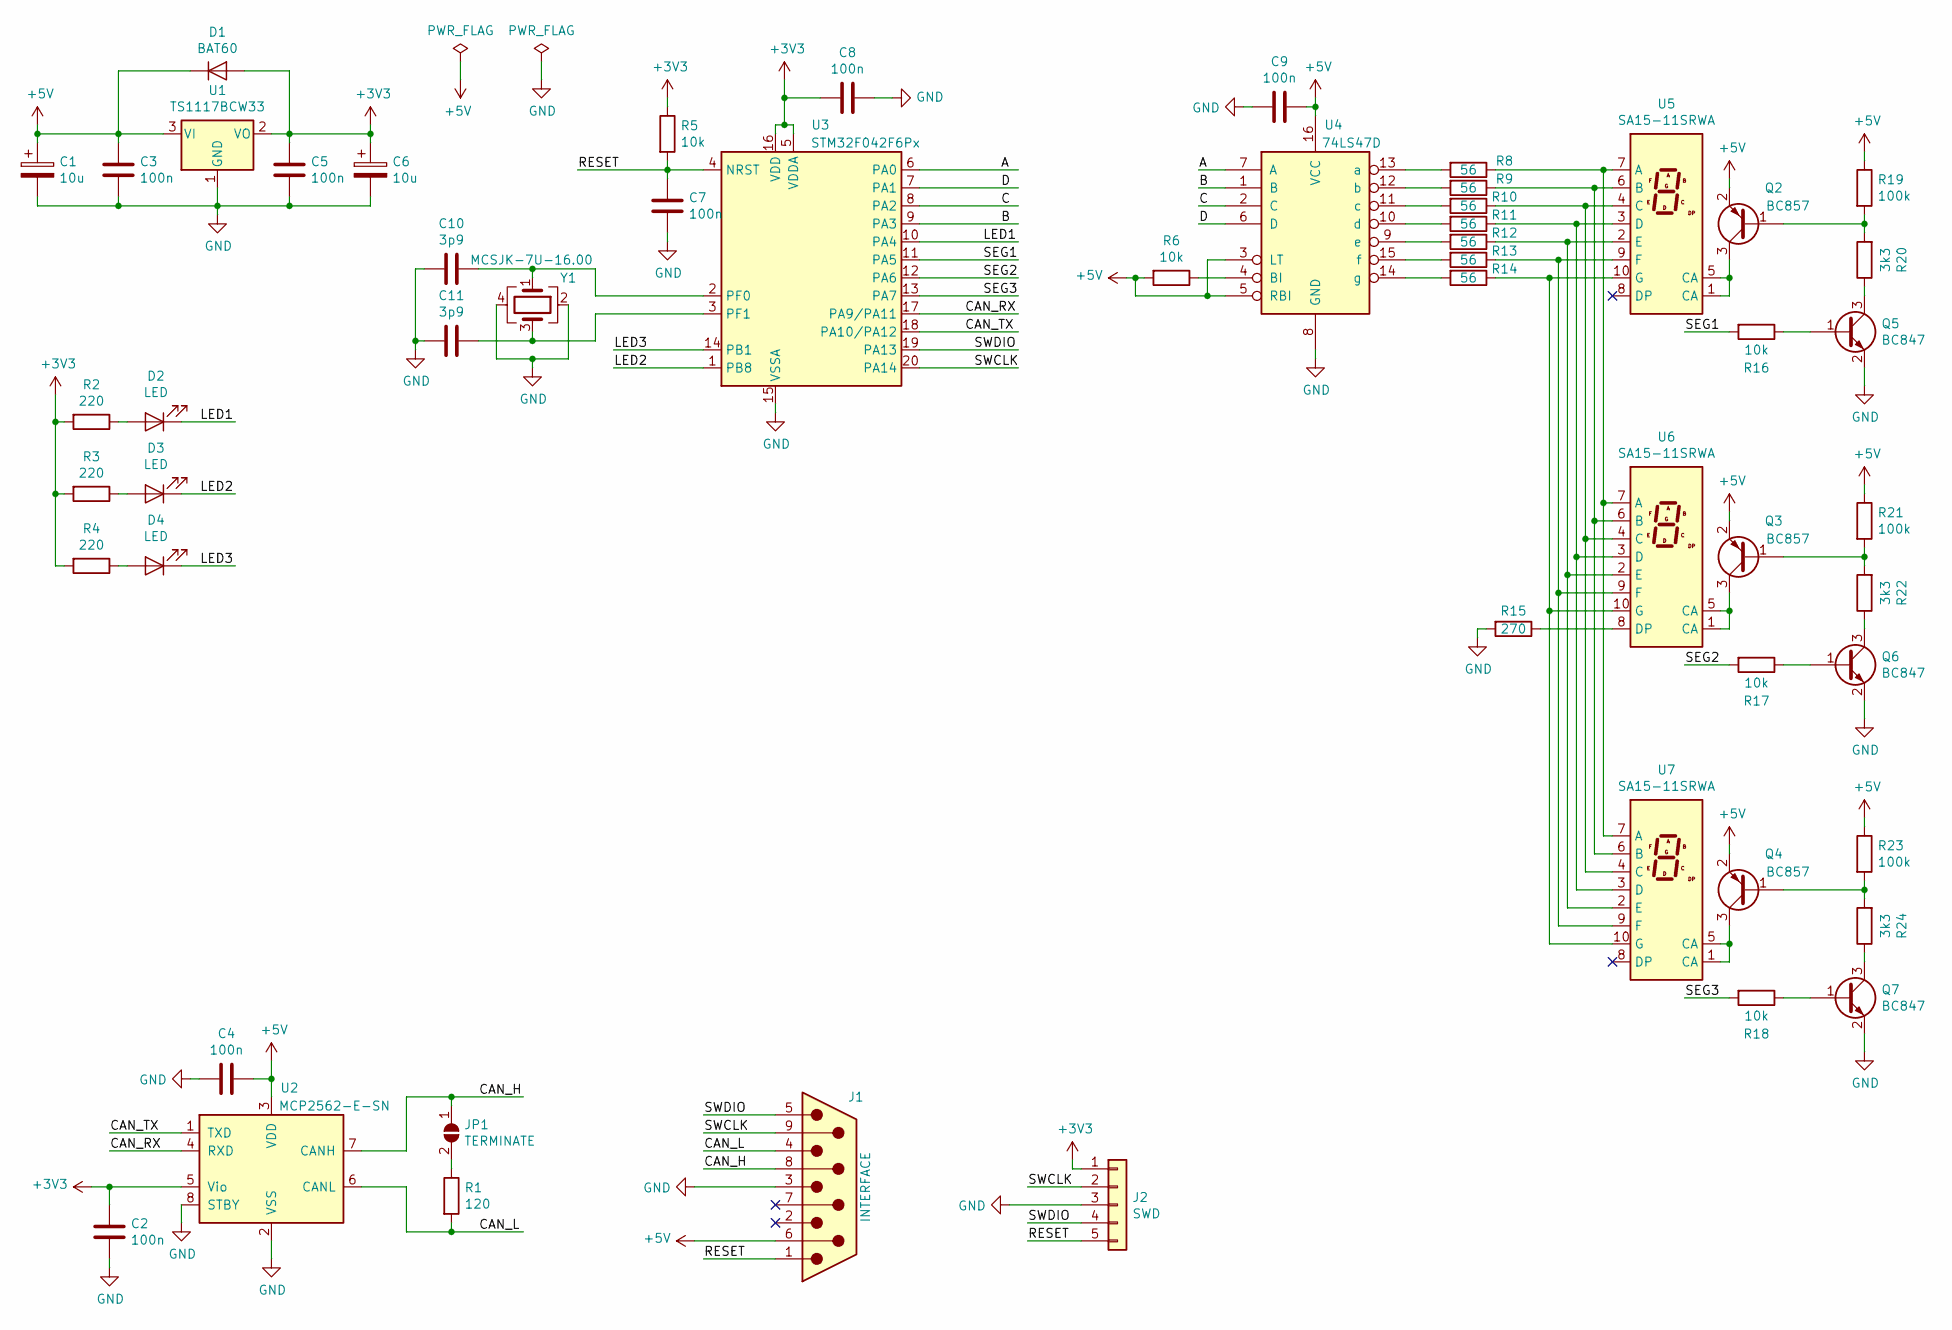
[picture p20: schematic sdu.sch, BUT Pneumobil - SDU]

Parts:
C1, C6: 10u; C_0805_2012Metric
C2, C3, C4, C5, C7, C8, C9: 100n; C_0805_2012Metric
C10, C11: 3p9; C_0805_2012Metric
D1: BAT60; D_SOD-323
D2, D3, D4: LED; LED_D5.0mm
J1: INTERFACE; DSUB-9_Female_Vertical_P2.77x2.84mm_MountingHoles
J2: SWD; PinHeader_1x05_P2.54mm_Horizontal
JP1: TERMINATE; SolderJumper-2_P1.3mm_Open_TrianglePad1.0x1.5mm
Q2, Q3, Q4: BC857; SOT-23
Q5, Q6, Q7: BC847; SOT-23
R1: 120; R_0805_2012Metric
R2, R3, R4: 220; R_0805_2012Metric
R5, R6, R16, R17, R18: 10k; R_0805_2012Metric
R8, R9, R10, R11, R12, R13, R14: 56; R_0805_2012Metric
R15: 270; R_0805_2012Metric
R19, R21, R23: 100k; R_0805_2012Metric
R20, R22, R24: 3k3; R_0805_2012Metric
U1: TS1117BCW33; SOT-223-3_TabPin2
U2: MCP2562-E-SN; SOIC-8_3.9x4.9mm_P1.27mm
U3: STM32F042F6Px; TSSOP-20_4.4x6.5mm_P0.65mm
U4: 74LS47D; SOIC-16_3.9x9.9mm_P1.27mm
U5, U6, U7: SA15-11SRWA; SA15-11
Y1: MCSJK-7U-16.00; Crystal_SMD_3225-4Pin_3.2x2.5mm

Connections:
+3V3: C2.1, C5.1, C6.1, C8.2, D1.2 (A), J2.1, R2.2, R3.2, R4.2, R5.1, U1.2 (VO), U2.5 (Vio), U3.5 (VDDA), U3.16 (VDD)
+5V: C1.1, C3.1, C4.1, C9.1, D1.1 (K), J1.6, Q2.2 (E), Q3.2 (E), Q4.2 (E), R6.2, R19.1, R21.1, R23.1, U1.3 (VI), U2.3 (VDD), U4.3 (LT), U4.5 (RBI), U4.16 (VCC)
/A: U3.6 (PA0), U4.7 (A)
/B: U3.9 (PA3), U4.1 (B)
/C: U3.8 (PA2), U4.2 (C)
/CAN_H: J1.8, JP1.1 (A), U2.7 (CANH)
/CAN_L: J1.4, R1.2, U2.6 (CANL)
/CAN_RX: U2.4 (RXD), U3.17 (PA9/PA11)
/CAN_TX: U2.1 (TXD), U3.18 (PA10/PA12)
/D: U3.7 (PA1), U4.6 (D)
/LED1: D2.1 (K), U3.10 (PA4)
/LED2: D3.1 (K), U3.1 (PB8)
/LED3: D4.1 (K), U3.14 (PB1)
/RESET: C7.1, J1.1, J2.5, R5.2, U3.4 (NRST)
/SEG1: R16.2, U3.11 (PA5)
/SEG2: R17.2, U3.12 (PA6)
/SEG3: R18.2, U3.13 (PA7)
/SWCLK: J1.9, J2.2, U3.20 (PA14)
/SWDIO: J1.5, J2.4, U3.19 (PA13)
GND: C1.2, C2.2, C3.2, C4.2, C5.2, C6.2, C7.2, C8.1, C9.2, C10.2, C11.2, J1.3, J2.3, Q5.2 (E), Q6.2 (E), Q7.2 (E), R15.2, U1.1 (GND), U2.2 (VSS), U2.8 (STBY), U3.15 (VSSA), U4.8 (GND), Y1.2, Y1.4
unnamed: C10.1, U3.2 (PF0), Y1.1
unnamed: C11.1, U3.3 (PF1), Y1.3
unnamed: D2.2 (A), R2.1
unnamed: D3.2 (A), R3.1
unnamed: D4.2 (A), R4.1
unnamed: JP1.2 (B), R1.1
unnamed: Q2.1 (B), R19.2, R20.2
unnamed: Q2.3 (C), U5.1 (CA), U5.5 (CA)
unnamed: Q3.1 (B), R21.2, R22.2
unnamed: Q3.3 (C), U6.1 (CA), U6.5 (CA)
unnamed: Q4.1 (B), R23.2, R24.2
unnamed: Q4.3 (C), U7.1 (CA), U7.5 (CA)
unnamed: Q5.1 (B), R16.1
unnamed: Q5.3 (C), R20.1
unnamed: Q6.1 (B), R17.1
unnamed: Q6.3 (C), R22.1
unnamed: Q7.1 (B), R18.1
unnamed: Q7.3 (C), R24.1
unnamed: R6.1, U4.4 (BI)
unnamed: R8.1, U5.7 (A), U6.7 (A), U7.7 (A)
unnamed: R8.2, U4.13 (a)
unnamed: R9.1, U5.6 (B), U6.6 (B), U7.6 (B)
unnamed: R9.2, U4.12 (b)
unnamed: R10.1, U5.4 (C), U6.4 (C), U7.4 (C)
unnamed: R10.2, U4.11 (c)
unnamed: R11.1, U5.3 (D), U6.3 (D), U7.3 (D)
unnamed: R11.2, U4.10 (d)
unnamed: R12.1, U5.2 (E), U6.2 (E), U7.2 (E)
unnamed: R12.2, U4.9 (e)
unnamed: R13.1, U5.9 (F), U6.9 (F), U7.9 (F)
unnamed: R13.2, U4.15 (f)
unnamed: R14.1, U5.10 (G), U6.10 (G), U7.10 (G)
unnamed: R14.2, U4.14 (g)
unnamed: R15.1, U6.8 (DP)

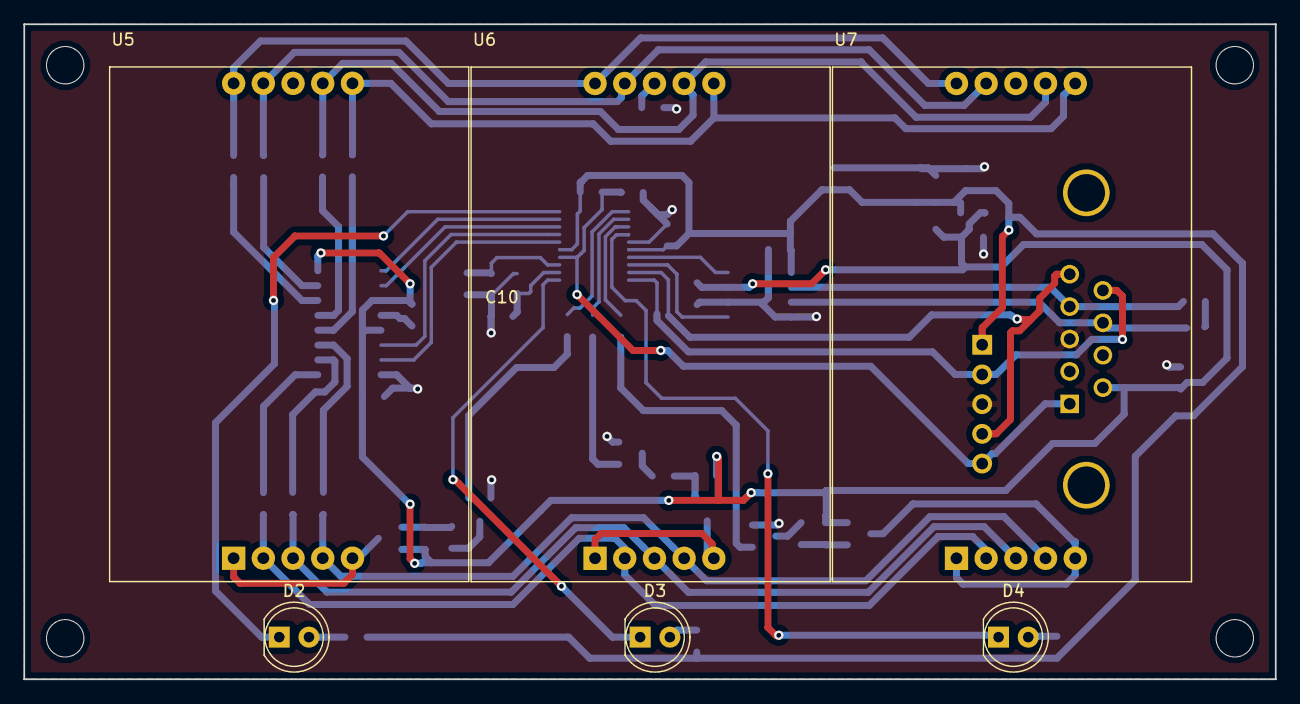
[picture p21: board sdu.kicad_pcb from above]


Board: 2 copper layers, 107.0 x 56.0 mm, 55 parts (49 on the bottom side), 54 nets.

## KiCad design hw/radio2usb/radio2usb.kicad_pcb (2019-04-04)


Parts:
C1, C5, C7: 10u; C_0805_2012Metric
C2, C3, C4, C6, C8: 100n; C_0805_2012Metric
D1: TX; LED_1206_3216Metric
D2: RX; LED_1206_3216Metric
J1: DEBUG; PinHeader_1x03_P2.54mm_Vertical
J2: SWD; PinHeader_1x05_P2.54mm_Vertical
J3: USB_A; USB_A_CNCTech_1001-011-01101_Horizontal
J4: Antenna; SMA_Amphenol_132134-11_Vertical
R1, R2: 220; R_0805_2012Metric
R3: 10k; R_0805_2012Metric
R4, R5: 22; R_0805_2012Metric
R6: 1k5; R_0805_2012Metric
U1: TS1117BCW33; SOT-223-3_TabPin2
U2: STM32F042F6Px; TSSOP-20_4.4x6.5mm_P0.65mm
U3: USB6B1; SOIC-8_3.9x4.9mm_P1.27mm
U4: RFM69HW; HOPERF_RFM69HW

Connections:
+3V3: C3.1, C5.1, C6.2, C7.1, C8.1, J2.1, R1.2, R2.2, R3.1, R6.1, U1.2 (VO), U2.5 (VDDA), U2.16 (VDD), U4.8 (3.3V)
+5V: C1.1, C2.1, J3.1 (VBUS), U1.3 (VI), U3.1 (VBUS), U3.8 (VBUS)
/CS: U2.14 (PB1), U4.15 (NSS)
/DEBUG_RX: J1.2, U2.9 (PA3)
/DEBUG_TX: J1.3, U2.8 (PA2)
/MISO: U2.12 (PA6), U4.13 (MISO)
/MOSI: U2.13 (PA7), U4.14 (MOSI)
/RESET: C4.1, J2.5, R3.2, U2.4 (NRST)
/RFM_IRQ: U2.7 (PA1), U4.2 (DIO0)
/RFM_RESET: U2.6 (PA0), U4.1 (RESET)
/RX_LED: D2.1 (K), U2.10 (PA4)
/SCK: U2.11 (PA5), U4.12 (SCK)
/SWCLK: J2.2, U2.20 (PA14)
/SWDIO: J2.4, U2.19 (PA13)
/TX_LED: D1.1 (K), U2.1 (PB8)
/USB_DM: R5.2, U2.17 (PA9/PA11)
/USB_DP: R4.2, R6.2, U2.18 (PA10/PA12)
GND: C1.2, C2.2, C3.2, C4.2, C5.2, C6.1, C7.2, C8.2, J1.1, J2.3, J3.4 (GND), J3.5 (Shield), J4.2 (Ext), U1.1 (GND), U2.15 (VSSA), U3.4 (GND), U3.5 (GND), U4.9 (GND), U4.11 (GND)
unnamed: D1.2 (A), R1.1
unnamed: D2.2 (A), R2.1
unnamed: J3.2 (D-), U3.7 (I/O1)
unnamed: J3.3 (D+), U3.6 (I/O2)
unnamed: J4.1 (In), U4.10 (ANA)
unnamed: R4.1, U3.3 (I/O2)
unnamed: R5.1, U3.2 (I/O1)



Board: 2 copper layers, 37.2 x 24.0 mm, 24 parts (3 on the bottom side), 25 nets.

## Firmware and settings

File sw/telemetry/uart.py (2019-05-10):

#!/usr/bin/python3
#
# Uart handling
#

import logging
import inspect
import sys
import serial
import threading
import crcmod
from comm import *
from pydispatch import dispatcher

UART_SOF = 0xff

BAUDRATE = 115200
PORT = "/dev/ttyUSB0"
UART_TIMEOUT_S = 0.5

# Receiving state machine
UART_STATE_START = 0
UART_STATE_LEN = 1
UART_STATE_DATA = 2
UART_STATE_CRC = 3

class Uart:
    def __init__(self):
        self.port = None
        self.log = logging.getLogger()#self.__class__.__name)
        self.thread = None

    def connect(self, port=PORT, baudrate=BAUDRATE):
        if self.port is not None and self.port.isOpen():
            self.log.warning("Serial port {} already open".format(port))
            return

        self.log.info("Opening serial port {} with baudrate {}".format(port, baudrate))
        try:
            self.port = serial.Serial(port, baudrate)
        except serial.serialutil.SerialException:
            self.log.error("Failed to open port %s", port)
            return False
        self.port.timeout = UART_TIMEOUT_S

        self.thread_run = True
        self.thread = threading.Thread(target=self._dataThread)
        self.thread.start()

        return True

    def disconnect(self):
        if self.port is None:
            return

        self.thread_run = False
        self.thread.join()

        self.log.info("Closing serial port")
        self.port.close()
        self.port = None

    def subscribe(self, cmd_id, callback):
        dispatcher.connect(callback, signal=cmd_id, sender=self)

    def _processData(self, buf):
        cmd = buf[0] & 0x3f
        self.log.debug('CMD = %02x, resp = %d, error = %d, data = %s',
                cmd, buf[0] & 0x80 != 0, buf[0] & 0x40 != 0,
                ''.join('%02X ' % int(b) for b in buf[1:]))

        msg = None
        for name, obj in inspect.getmembers(sys.modules[CommStructure.__module__]):
            try:
                if obj.CMD_ID == cmd:
                    self.log.debug("Found class %s for decoding cmd %d", name, cmd)
                    msg = obj()
                    break
            except AttributeError:
                pass

        if msg != None:
            msg.decode(buf[1:])
            dispatcher.send(signal = cmd, sender = self, msg = msg)
        else:
            self.log.debug("Class for decoding cmd %d not found", cmd)

    def _crcVerify(self, crc, buf):
        # calculate crc for given buffer and return true if result is same as crc
        crcfunc = crcmod.predefined.mkCrcFun("crc-8")
        if crc != crcfunc(bytes(buf)):
            return False
        return True

    def _dataThread(self):
        # thread for receiving data over uart
        state = UART_STATE_START
        length = 0
        count = 0
        buf = []

        while self.thread_run:
            c = self.port.read(1)
            #timeouted
            if len(c) == 0:
                state = UART_STATE_START
                continue
            c = int.from_bytes(c, byteorder='little')

            if state == UART_STATE_START:
                if c == UART_SOF:
                    state = UART_STATE_LEN
                    length = 0
                    count = 0
                    crc = 0
                    buf = []
            elif state == UART_STATE_LEN:
                state = UART_STATE_DATA
                length = c
            elif state == UART_STATE_DATA:
                buf.append(c)
                count += 1
                if count == length:
                    state = UART_STATE_CRC
            elif state == UART_STATE_CRC:
                state = UART_STATE_START
                if self._crcVerify(c, [UART_SOF, length]+buf):
                    self._processData(buf)
                else:
                    self.log.warn("Received uart crc does not match")
            else:
                state = UART_STATE_START
                self.log.error("Entered incorrect uart state {}".format(state))

if __name__ == '__main__':
    conn = Comm()
    comm.connect()
    comm.disconnect

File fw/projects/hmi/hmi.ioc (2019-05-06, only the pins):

Mcu.UserName=STM32F412VETx
PA1.GPIO_Label=ADC_5V
PA1.Signal=ADCx_IN1
PA10.GPIO_Label=GPS_RXD
PA10.Signal=USART1_RX
PA11.Signal=USB_OTG_FS_DM
PA12.Signal=USB_OTG_FS_DP
PA13.Signal=SYS_JTMS-SWDIO
PA14.Signal=SYS_JTCK-SWCLK
PA15.GPIO_Label=SD_DETECT
PA15.Signal=GPIO_Input
PA2.GPIO_Label=DEBUG_TXD
PA2.Signal=USART2_TX
PA3.GPIO_Label=DEBUG_RXD
PA3.Signal=USART2_RX
PA4.GPIO_Label=LED_USER
PA4.Signal=GPIO_Output
PA5.GPIO_Label=LED_SYS_ACTIVE
PA5.Signal=GPIO_Output
PA7.GPIO_Label=BTL1
PA7.Signal=GPIO_Input
PA8.GPIO_Label=BME_CS
PA8.Signal=GPIO_Output
PA9.GPIO_Label=GPS_TXD
PA9.Signal=USART1_TX
PB0.GPIO_Label=BTR1
PB0.Signal=GPIO_Input
PB1.GPIO_Label=BTR2
PB1.Signal=GPIO_Input
PB12.GPIO_Label=LCD_T_CS
PB12.Signal=GPIO_Output
PB13.GPIO_Label=DISP_SCK
PB13.Signal=SPI2_SCK
PB14.GPIO_Label=DISP_MISO
PB14.Signal=SPI2_MISO
PB15.GPIO_Label=DISP_MOSI
PB15.Signal=SPI2_MOSI
PB2.GPIO_Label=BTR3
PB2.Signal=GPIO_Input
PB4.GPIO_Label=BUZZER
PB4.Signal=S_TIM3_CH1
PB6.Signal=I2C1_SCL
PB7.Signal=I2C1_SDA
PB8.GPIO_Label=CAN_TX
PB8.Signal=CAN1_RX
PB9.GPIO_Label=CAN_RX
PB9.Signal=CAN1_TX
PC10.Signal=SDIO_D2
PC11.Signal=SDIO_D3
PC12.Signal=SDIO_CK
PC14-OSC32_IN.Signal=RCC_OSC32_IN
PC15-OSC32_OUT.Signal=RCC_OSC32_OUT
PC4.GPIO_Label=BTL2
PC4.Signal=GPIO_Input
PC5.GPIO_Label=BTL3
PC5.Signal=GPIO_Input
PC6.GPIO_Label=LCD_REST
PC6.Signal=GPIO_Output
PC7.GPIO_Label=LCD_SD_CS
PC7.Signal=GPIO_Output
PC8.Signal=SDIO_D0
PC9.Signal=SDIO_D1
PD0.Signal=FSMC_D2_DA2
PD1.Signal=FSMC_D3_DA3
PD10.Signal=FSMC_D15_DA15
PD11.GPIO_Label=LCD_T_IRQ
PD11.Signal=GPIO_Input
PD12.GPIO_Label=LCD_F_CS
PD12.Signal=GPIO_Output
PD13.GPIO_Label=LCD_RS
PD13.Signal=FSMC_A18
PD14.Signal=FSMC_D0_DA0
PD15.Signal=FSMC_D1_DA1
PD2.Signal=SDIO_CMD
PD4.Signal=FSMC_NOE
PD5.Signal=FSMC_NWE
PD7.GPIO_Label=LCD_CS
PD7.Signal=FSMC_NE1
PD8.Signal=FSMC_D13_DA13
PD9.Signal=FSMC_D14_DA14
PE1.GPIO_Label=RFM_RESET
PE1.Signal=GPIO_Output
PE10.Signal=FSMC_D7_DA7
PE11.Signal=FSMC_D8_DA8
PE12.Signal=FSMC_D9_DA9
PE13.Signal=FSMC_D10_DA10
PE14.Signal=FSMC_D11_DA11
PE15.Signal=FSMC_D12_DA12
PE2.GPIO_Label=COMM_SCK
PE2.Signal=SPI4_SCK
PE3.GPIO_Label=RFM_CS
PE3.Signal=GPIO_Output
PE4.GPIO_Label=RFM_IRQ
PE4.Signal=GPIO_Input
PE5.GPIO_Label=COMM_MISO
PE5.Signal=SPI4_MISO
PE6.GPIO_Label=COMM_MOSI
PE6.Signal=SPI4_MOSI
PE7.Signal=FSMC_D4_DA4
PE8.Signal=FSMC_D5_DA5
PE9.Signal=FSMC_D6_DA6

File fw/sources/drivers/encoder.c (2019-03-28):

/*
    BUT pneumobil - Copyright (C) 2018 Jakub Kaderka.

    This file is part of BUT pneumobil.

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
    You should have received a copy of the GNU General Public License
    along with this program.  If not, see <http://www.gnu.org/licenses/>.
*/

/**
 * @file    encoder.c
 * @brief   Quadruple encoder driver
 *
 * @addtogroup drivers
 * @{
 */

#include <hal.h>

#include "drivers/encoder.h"

#define QEID JOIN(QEID, TIM_ROT_ENC_A)

static void Encoderdi_Start(bool invert)
{
    static QEIConfig config;
    config.mode = QEI_MODE_QUADRATURE;
    config.resolution = QEI_SINGLE_EDGE;
    if (invert) {
        config.dirinv = QEI_DIRINV_TRUE;
    } else {
        config.dirinv = QEI_DIRINV_FALSE;
    }
    config.overflow = QEI_OVERFLOW_WRAP;

    qeiStart(&QEID, &config);
    qeiEnable(&QEID);
}

int16_t Encoderd_Get(void)
{
    return qeiGetCount(&QEID);
}

void Encoderd_Set(int16_t value)
{
    qeiSetCount(&QEID, value);
}

void Encoderd_InvertDirection(void)
{
    qeiDisable(&QEID);
    qeiStop(&QEID);
    Encoderdi_Start(true);
}

void Encoderd_Init(void)
{
    Encoderdi_Start(false);
}

/** @} */

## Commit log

2018-09-16 Added naming conventions. board names and pneumatic components specs
2018-09-16 Renamed pneumatic to ECU (engine control unit)
2018-09-23 Added initial draft of eeprom driver
2018-09-23 Added DAC driver
2018-09-26 Added timing calculation for i2c
2018-09-28 Added mutex to uart link sending
2018-09-28 Generate board config from stm32cubemx project
2018-10-14 Added pcb for ECU
    [ecu.kicad_pcb, ecu.sch, inputs.sch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]
2018-10-19 Generated gerbers for ECU
    [ecu.kicad_pcb]
2018-10-19 Added buttons handling
2018-10-27 Added engine driver
2018-11-02 Updated few resistors/capacitors values on board
    [ecu.kicad_pcb, ecu.sch, inputs.sch]
2018-11-25 Added schematics for all parts
    [buttons.sch, cur_sensor.sch, driver.sch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]
2018-12-06 Added HMI and SDU boards
    [hmi.kicad_pcb, hmi.sch, power_supply.sch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]
2018-12-10 Updated power supply in HMI
    [hmi.kicad_pcb, hmi.sch, power_supply.sch]
2018-12-10 Don't wait for endstop hit in init
    When the piston len is known, just set encoder to middle of the length
    and return from init, during first cycle the correct value will be set
    once the endstop is hit.
2018-12-23 Added pressure sensor to hmi
    [buttons.sch, hmi.kicad_pcb, hmi.sch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]
2019-01-02 Added can driver and defines for joining two string for easier peripheral selection
2019-01-02 Added log source for drivers
2019-01-02 Abstracted the encoder interface
2019-01-02 Added speed counter driver
2019-01-02 Added adc driver
2019-01-03 Generalized the uart device selection
2019-01-03 Added generated board file
2019-01-13 Fixed can filtering
2019-01-13 Fixed can filters - broadcast must be received all the time
2019-01-18 Added can and I2C support for stm32f4xx
2019-01-27 Added forgotten i2c initialization
2019-01-28 Added handling of the card insertion and removal
2019-01-29 Added RTC driver
2019-01-30 Increased amount of can receive mailboxes to match amount of boards used
2019-01-30 Added gearbox state and horn button to ecu_io
2019-01-30 Added reading piston position for external modules to ecu
2019-01-31 Added support for inverting the endstops
2019-01-31 Implemented switching race modes by button press
2019-02-04 Added uGFX driver
2019-02-11 Fixed chibios hal drivers initialization (config must be static)
    [encoder.c, i2c.c, spi.c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]
2019-02-11 Fixed input type for LCD touch screen controller IRQ
    [hmi.ioc]
2019-02-14 Fixed writing to eeprom
    [eeprom.c, i2c.c]
2019-02-14 Fixed adc
2019-02-14 Switched optimizations back on - no optimizations were causing system tasks stack overflow,...
2019-02-14 Reduced ugfx lcd driver timing
2019-03-07 Fixed adc reference voltage calculation (bug in datasheet)
    [adc.c]
2019-03-07 Reinit adc on timeout (adc in locked state)
2019-03-07 Decreased can timeout to avoid blocking for too long in case the can is not connected
2019-03-07 Avoid blocking sender thread when the execution time is too long
2019-03-07 Fixed reading status info
    [application.c]
2019-03-07 Increased can and uart drivers stacks
2019-03-08 Fixed reading status data
    [application.c]
2019-03-08 Fixed setting can filters
2019-03-09 Added board for radio2usb converter
    [radio2usb.kicad_pcb, radio2usb.sch]
2019-03-10 Updated schematic to latest changes in usb protection ic
    [ecu.kicad_pcb, ecu.sch, hmi.kicad_pcb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]
2019-03-11 Added crystal for all can equipped boards
    [ecu.kicad_pcb, ecu.sch, inputs.sch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]
2019-03-12 Fixed sdc driver stack overflow, fixed insertion callback not called
2019-03-12 Create new log file on mode switching
2019-03-13 Fixed printing flaots to log
2019-03-17 Fixed printing date on race screen
2019-03-25 Save current mode to eeprom
2019-03-25 Updated SDU board
    [sdu.kicad_pcb, sdu.sch]
2019-03-27 Fixed endstop inversion
2019-03-28 Removed message on both endstop on (tons of messages will block other, more important)
2019-03-28 Reduced resolution of encoder for lower counting frequency
2019-03-28 New stm32cube output
2019-03-28 Script for reading log messages from uart
2019-03-28 Fixed dry run printing
2019-03-28 Fixed adc conversion - depth must be 1 for single result buffer
    [adc.c]
2019-03-28 Initialize memory pool before starting log thread
2019-03-28 Open both valves to for venting out
2019-03-28 Add dual valves mode changing
2019-03-29 Valve direction control updated to match current connection
2019-03-29 Increased uart stack
2019-03-29 Fixed ecu initialization (getpos was clearing the encoder)
2019-04-02 Fixed values of few components on psu board
    [psu.kicad_pcb, psu.sch]
2019-04-04 Made space around connectors screw for nut
    [hmi.kicad_pcb]
2019-04-04 Generated gerbers for manufacturing
    [ecu.kicad_pcb, hmi.kicad_pcb, psu.kicad_pcb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]
2019-04-10 Added driver for rfm69 modules
2019-04-18 Remad shared GPIO on STM32F042 to correct pin
2019-04-18 Added note about config option bits for stm32F042
2019-04-19 Use on board crystall for psu, sdu and ecu
2019-04-19 Fixed initial gpio state
    [radio2usb.ioc]
2019-04-19 Updated clock scheme in sdu stm32cubemx project
2019-04-19 Commented out gearbox2 as it's not present on the new board
2019-04-20 Fixed direction select on throttle press
2019-04-20 show module uptime instead of temperature
2019-04-20 Fixed printing pct in status screen
2019-04-20 Added printing battery info to tabs header
2019-04-20 Added piston len reset button to debug screen (without logic behind yet)
2019-04-22 Fixed pin remmaping - moved to correct init function
2019-04-25 Added on select event to screens, added reading and resetting piston len
    [application.c, comm.h]
2019-04-25 Fixed current measurement by psu
2019-04-30 Fixed diode polarity
    [psu.kicad_pcb, psu.sch]
2019-05-01 Inverted brake logic
2019-05-01 Fixed data type in rfm driver
    [rfm69.c]
2019-05-02 Set default value to piston len when rot encoder died
2019-05-02 Modified valve control to match physical wiring
2019-05-02 Updated valve control - back valves are inverted as it was easier to update code than rewire the connector
2019-05-04 Fixed opamp on ecu board to one with correct power range
    [ecu.kicad_pcb, outputs.sch]
2019-05-04 Reduced resistors for horn and brake buttons to switch on mosfets
    [ecu.kicad_pcb, inputs.sch]
2019-05-04 Save current mode only for non debug modes
2019-05-06 Control error led from console warn status
    [hmi.ioc]
2019-05-07 Fixed interrupt stack size for ecu
2019-05-07 Fixed inputs reading, workarounded horn button
2019-05-07 Reboot if assert fails (only the current thread hangs, others are still running)
2019-05-08 Fixed closing valves
2019-05-08 Initialize spi before rf module
2019-05-09 Fixed opening serial port from telemetry
    [gui.py]
2019-05-09 Fixed uart in telemetry module
    [uart.py]
2019-05-09 Don't interrupt the cycle on brake press
2019-05-10 Fixed unpacking telemetry data
    [comm.py]
2019-05-10 Run gui updates in gui thread
2019-05-12 Added final specs
    [config.ods, protocols.ods]

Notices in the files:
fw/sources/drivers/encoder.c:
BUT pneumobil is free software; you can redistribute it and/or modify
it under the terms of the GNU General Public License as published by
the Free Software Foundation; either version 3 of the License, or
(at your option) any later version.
